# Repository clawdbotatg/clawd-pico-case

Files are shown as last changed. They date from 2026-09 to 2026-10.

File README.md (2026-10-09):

# clawd-pico-case

## What to print (v1.9)

Files are in [`stl/current/`](stl/current/README.md). One case:

| File | Copies | Colour |
|---|---|---|
| [`lid.stl`](stl/current/lid.stl) | 1 | White |
| [`base.stl`](stl/current/base.stl) | 1 | Black |
| [`joystick.stl`](stl/current/joystick.stl) | 1 | Grey |
| [`button.stl`](stl/current/button.stl) | 4 | 2 grey (middle two), 1 green (top right), 1 red (bottom right) |

All PETG. 0.16 mm layers, 4 walls, no supports, no brim, no raft. Lid:
elephant-foot compensation 0.15. Don't rotate the parts; they are already the
right way up (lid face down, base floor down, caps flange down).

**Atomic Wedgie** (RP2040-Plus with a battery): red base with a battery
channel and a black RESET button. See [`stl/atomic-wedgie/`](stl/atomic-wedgie/README.md).

`full-set.stl` is all seven parts on one plate, in one colour. Skip it for a
coloured case.

Everything else in `stl/`, `renders/` and `prints/` is old tests, kept as the
design record. Don't print it.

An MIT-licensed 3D-printed case for a USB-C RP2040 Pico clone (the pink board) plugged into a
Waveshare Pico-LCD-1.3 (240x240 screen, joystick, four buttons). Buttons and
joystick get caps. Made to be printed and sold.

A micro-USB Pico fits too: Austin tested one in the v1.9 case on 2026-10-07,
and the cable and BOOTSEL both work
([log](prints/2026-10-07-micro-usb-fit.md)).

## Why this repo exists

The cases we used before are not ours to sell:

- Tomáš Plass, "Waveshare Pico 1.3 LCD Case", Printables model 1322102, CC BY-NC 4.0.
- Zez0000, "Raspberry Pi Pico 2 Case - Waveshare 1.3\" LCD", MakerWorld model
  3230142, CC BY-NC 4.0. A remix of the Plass case with button and joystick caps.
- Every case file in the `austintgriffith/picowallet` repo derives from those two.

NC means no commercial use. So this case is designed from scratch, from the
hardware and its datasheets only, and released under MIT.

## The rule

Nobody working on this repo opens the designs above, or any other case for
this board, while designing. Not the files, not the photos, not the listing
pages. Every dimension comes from a caliper or a datasheet and is written down
in `MEASUREMENTS.md` before it is used. Every design input is logged in
`PROVENANCE.md`. See `PROCESS.md` for the full protocol and `CLAUDE.md` for the
rules AI agents follow here.

A case for this board will look like the others because the board decides the
size, the screen window, the button holes, the joystick hole and the USB
cutout. That is fine. Shape forced by the hardware is not anyone's property.
What we do not copy is their files and their styling choices.

## Layout

| Path | What |
|---|---|
| `PROCESS.md` | The clean-room protocol, phase by phase |
| `SOURCES.md` | Allowed inputs and forbidden inputs |
| `MEASUREMENTS.md` | The measurement sheet. Every number the design uses |
| `PROVENANCE.md` | Dated log of every design input and who added it |
| `DESIGN.md` | Design decisions, written during the design phase |
| `REPORT.md` | Current state: measurements, design, confidence, open questions |
| `cad/` | build123d source. The design is the source, not the STL |
| `renders/` | `viewer.html`: every part in 3D in a browser, rebuilt from source |
| `research/` | Notes on method: how to get real hardware into 3D |
| `stl/` | Built outputs |
| `prints/` | Print log: what was printed, what fit, what did not |
| `measurements/` | Caliper photos and datasheet drawings |

## Development history (superseded by v1.0)

**Latest: low-lid V3 review, with the lid 1 mm above the glass.**
[Interactive model](renders/v3-low/viewer.html) · [Low-lid design and limitations](reports/2026-09-25-low-lid-experiments.md).
Rear retaining tab replaces the failed side-tab experiment. Not print-approved.
`stl/print/` still contains the OLD tall draft; do not print those files.

### Superseded tall V3 review

**V3 is ready for browser review only; not approved for printing.**
[Interactive model](renders/viewer.html) · [V3 changes and limitations](reports/2026-09-25-v3-review.md).
Flat lid (+4 mm uniformly), restored earlier joystick interface, internal lip,
closed USB port without the lid tab. No V3 print request has been sent.

### Earlier V2 result

**V2 failed its physical fit test. Do not reprint unchanged.**
[What worked, what failed, and correction goals](reports/2026-09-25-v2-review.md).
The V2 description below records the submitted design, not a ready replacement.

Saved designs and print history: [iteration register](ITERATIONS.md).

V1 feedback is [saved with photos](prints/2026-09-24-v1-feedback.md).
V2 / R5 implements all five changes: captive ball joystick, pry notches,
higher/tighter USB-C, wider/taller rectangular buttons and scan-positioned
bottom button access. Fit-test candidate; physical fit unverified. Original geometry;
no third-party case models used. The current target is the measured pink
USB-C board, not an official Pico W/Pico 2 W.

See [V2 preview](renders/r5-preview.png), [interactive assembly](renders/viewer.html),
and [critical review / assembly instructions](REPORT.md). R4 was submitted
to the print inbox; a hold/superseded request was subsequently posted.
Operator acknowledgment and V1's exact printed commit remain unconfirmed.
V2 dispatch and eventual result are recorded in [its print log](prints/2026-09-24-v2.md).
CAD validation is not physical validation; remaining measurements are in the report.

## Build

With Python 3.12 and dependencies in requirements.txt:

```sh
python -m venv .venv
.venv/bin/pip install -r requirements.txt
.venv/bin/python cad/v1_production.py
```

This checks the v1.0 geometry, then writes `stl/v1.0/` and `renders/v1.0/`
(STEP, viewer, validation and hashes). `cad/build.py` and `stl/print/` belong
to the old R4/R5 prototype. Do not print them.

## License

MIT. See `LICENSE`. "Raspberry Pi" and "Waveshare" are their owners'
trademarks. This case is made for their boards and says so descriptively. It
carries no logo but our own.

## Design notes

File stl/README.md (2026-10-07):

**To print a case, use [`current/`](current/README.md). Nothing else here.**

Every other file and folder in `stl/` is an old test, kept as the design
record. `print/` and the loose STLs in this folder are the first prototype
(2026-09-25), not the current case.

Built outputs only; run `.venv/bin/python cad/build.py` from repository root.
Never hand-edit meshes. MIT, like the original source.

`print/` holds base, lid, four button caps, and default joystick cap in print
orientation. Separate button solids on the bed. `fit_samples/` holds alternate
joystick caps named for socket width; try largest first without forcing.
Top-level STL/STEP uses assembled positions and includes illustrative hardware.
`manifest.json` records source/output SHA-256 hashes and tool version.
R4 is an unprinted prototype; print/assembly details in REPORT.md.

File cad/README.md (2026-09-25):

Original build123d CAD. Read `../CLAUDE.md` and `../PROCESS.md` first.
Hardware inputs and R4 choices cite `../MEASUREMENTS.md`; reasons in DESIGN.md.

From repository root: `.venv/bin/python cad/build.py`.
`params.py` defines hardware/choices; `model.py` constructs parts;
`validate.py` checks collision/motion scenarios; `render.py` produces a static
preview from CAD tessellation; `build.py` audits then exports all outputs.
Dependencies are pinned in requirements.txt. Validation is conditional on the
recorded measurements and explicit assumptions; see REPORT.md before printing.

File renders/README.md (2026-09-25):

Generated by `.venv/bin/python cad/build.py` from repository root:

- `viewer.html`: interactive assembly/explode; requires network for three.js.
- `r4-preview.png`: static CAD-derived assembly and interior views.
- `validation.json`: geometric checks, unresolved issues and source hashes.

Images use illustrative hardware proxies, not third-party models. Neither
a rendering nor a passing nominal collision check proves physical fit.

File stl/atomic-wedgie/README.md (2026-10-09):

# Atomic Wedgie: print this

For a Waveshare RP2040-Plus with a battery. Same case as `stl/current/`, with
a different base: a channel in the end wall (away from the USB) for the
battery plug and wire, a BOOT pin hole, and a RESET button.

| File | Copies | Colour |
|---|---|---|
| `base.stl` (this folder) | 1 | Red |
| `reset-button.stl` (this folder) | 1 | Black |
| `../current/lid.stl` | 1 | White |
| `../current/joystick.stl` | 1 | Grey |
| `../current/button.stl` | 4 | 2 grey (middle two), 1 green (top right), 1 red (bottom right) |

All PETG. 0.16 mm layers, 4 walls, no supports, no brim, no raft. Don't
rotate the parts (base floor down, caps flange down).

Assembly: drop the RESET button into its hole from inside the base, flange
up, before the board goes in.

Source: base `cad/aw2_base.py`, RESET button `cad/aw_reset_v3.py`.

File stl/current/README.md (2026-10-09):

# Print this: v1.9 case

| File | Copies | Colour |
|---|---|---|
| `lid.stl` | 1 | White |
| `base.stl` | 1 | Black |
| `joystick.stl` | 1 | Grey |
| `button.stl` | 4 | 2 grey (middle two), 1 green (top right), 1 red (bottom right) |

All PETG. 0.16 mm layers, 4 walls, no supports, no brim, no raft. Lid:
elephant-foot compensation 0.15. Don't rotate the parts; they are already the
right way up (lid face down, base floor down, caps flange down).

`full-set.stl` is all seven parts on one plate, in one colour. Skip it for a
coloured case.

Everything else in `stl/` is old test parts. Don't print it.
Change log: [HISTORY.md](HISTORY.md).

Atomic Wedgie (RP2040-Plus with a battery): different base, red, plus a RESET button. See `../atomic-wedgie/`.

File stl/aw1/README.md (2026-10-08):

# Atomic Wedgie base v1 (RP2040-Plus with a battery)

`base-floor-down.stl`, red PETG. Battery plug slot, BOOT pin hole, and a hole
for a RESET button: print one more `stl/current/button.stl` in red and drop it
in from inside before the board. Lid, joystick and buttons from `stl/current/`.

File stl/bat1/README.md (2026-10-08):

# Battery base (RP2040-Plus with a battery)

`base-floor-down.stl`: the v1.7 base with a 5 × 1 mm slot in the end wall
away from the USB, for the battery plug and wire. Use it with the normal lid,
joystick and buttons from `stl/current/`. Red PETG for the Atomic Wedgie,
same print settings as the case.

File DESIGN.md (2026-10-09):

# Current: V3 fitted shells

J2 socket-first trial: preserve J1 exterior; roundØ3×1 deep then existing
2.01 square×2 deep, exactly as Austin requests. Print cap only before lowering
lid. Pending lowered-lid/hole-centre changes must not alter old print files.

SUPERSEDED by V3-FLAT: whole outer face atz5.1, print FACE DOWN, no supports
or raft. Austin explicitly allows greater screen depth for this trial.
Builder cad/v3_flat.py; reuse button/joystick geometry; lid-only correction.
See JOYSTICK-REVIEW.md for current status; upright plan below is historical.

Complete review and evidence: JOYSTICK-REVIEW.md. Builder cad/v3_fit.py.
Reuse V2 button caps and unchanged J1 joystick; only base/lid print.
Closed V2-aligned USB aperture, no fin; retain pry/reset. Low screen side
rails, local J1-height joystick roof and V2-height button deck. Upright lid
print intent, no supports/raft; mandatory slice review. Historical D7/D8
below are rejected designs, not the current print candidate.

# Historical V3 low-lid revision — D7/D8

Original MIT geometry from this repository's hardware measurements and
Austin's feedback. No external case geometry. Review only, no print approval.

Hard constraint: lid top is glass top +1 mm, z3.05. No joystick collar or
uniform case raise. The rejected tall draft remains saved in v3-review-1.

D7 side retaining tabs cleared5 degrees but failed16 ten-degree lid cases;
that unsuccessful experiment is saved in commit2587340.

D8 uses one rear arm/heel on the joystick cap. The heel is behind the PCB
edge, allowing downward tilt into a local interior pocket, without changing
case height. Earlier full-case4010773 lower socket/neck remain unchanged.
V2 ball diameter7 and small top print flat remain. The cap is still installed
before the lid. The rear heel's thin sections need slicer and strength review.

Button retaining wings now sit beside the switches, below the plunger tops.
The central underside contacts each plunger at measured z2.61. Outside cap
footprint and1.8 mm protrusion remain. Flat top-down printing is planned.

Keep V2-aligned closed USB port, no external lid fin, successful pry notches
and bottom access. Changes and all trial coordinates are recorded in
MEASUREMENTS.md. Required motion scenarios include the full10 degrees,
presses, both pivot assumptions and cap/base/PCB clearance. Inherited
socket/neck versus guessed metal-body collisions remain disclosed.

See reports/2026-09-25-low-lid-experiments.md. Browser review comes before
printing, and no new print artifacts have been produced for this revision.
# J1 isolated joystick test — 2026-09-25

See JOYSTICK-REVIEW.md for the complete current review packet. Original
round-lip cap plus hand-held lid gauge only; D8 rear arm rejected. J1 preserves
the selected V1 socket, has known10-degree motion failures, and is not sent
to the printer. Full-case geometry is unchanged.
## J3 / L1 trial — 2026-09-25

Widen round socket to Austin's 3.50 × 1.10 mm; keep square 2.01 × 2.00 mm
and exterior unchanged. Lower whole flat face 0.90 mm to z4.20, pocket roof
to z3.50. Existing buttons limit further lowering: 0.64 mm roof now remains.
No local boss, supports, USB fin, new base or new buttons. Lip height z2.45
is Austin's estimate for visualization, not proven seating. Iteratively find
motion limit then back off. Full details in JOYSTICK-REVIEW.md.
## L2 / J2 authorized physical trial — 2026-09-25

Move L1 upper roof down 1.00 mm, retaining roof thickness. Keep lower wall
geometry through original glass-clearance height and union translated upper
geometry; preserve contacts, mating skirt and snaps. Face z3.20, joystick
underside z2.50, button underside z2.56. Same base/buttons; exact J2 socket.
User accepts possibly unsuccessful fit; predicted overlaps remain in report,
not suppressed or counted as passes. Print face down with no supports/raft.
## L3 opening correction — 2026-09-25

L2 failed physical closure. Restore L1 thickness/height/pockets and shift only
round opening 1.00 mm toward LCD (CAD negative Y). Fill old throat crescent,
recut at new centre; retain 8 mm diameter and existing lip cavity. No base,
button or joystick changes. Print lid only, face down, supports/raft off.
## L4 alignment refinement

L3 physically overshot. New aperture centre is original X+0.30, Y-0.50:
halfway back from L3 and slightly photo-up with LCD on right. Keep diameter,
height and lip pocket unchanged. Photo-up magnitude is explicitly a trial
choice, not a calibrated measurement. Prepared lid only, not dispatched.
## S1 stronger walls / lower seam — review before printing

Austin's IMG_0834 shows exterior flexible bands and catch windows; he reports
bending during print removal. Replace these with continuous walls and blind
internal detents. Move visible seam to one-third of total height from bottom.
Make walls 3 mm by growing outward, preserving internal board clearances and
fitted control roof heights. A continuous thick perimeter/deeper walls are
intended to improve stiffness without lowering the control pockets again.

Joint uses 3 mm overlap, 1.4 mm socket wall, 0.2 mm gap, 1.4 mm tongue;
small bidirectional ramp catches allow removal without exposed flexible slots.
Minimum exterior skin at blind catches is 1.05 mm. One pry notch remains.
Actual strength, release force and cycle life require testing.

Transfer board support to two base-carried internal rails because the original
wall shelf would otherwise belong to the upper shell and obstruct assembly.
Retain USB port/reset location; extend outside cable recess to compensate for
added wall thickness. L4 opening offset retained. New matching shell pair;
does not fit old base. Interactive review requested; no printer dispatch.
## S2 closure and tactile refinement

S1 field feedback: loose vertical joint and indistinct button tops. Replace
base only: preserve body/rails/ports, swap symmetric triangular detents for
deeper catches with flat holding face, short vertical nose and insertion ramp.
Use existing lid-pocket lower edge to reduce nominal axial travel to0.04 mm;
projection0.50 consumes0.30mm socket flex and leaves0.05mm recess spare.
No claimed FDM accuracy or tested retention force. Small catch overhang needs
slice review. Keep existing lid/pry notch; no new exterior slots.

Caps retain V2 interface, gain0.50mm height and1.20mm rolled top edges to
separate finger contact areas. No change to button spacing or flange height.
Print five parts in PLA; defer PETG/colors until fit iterations finish.
## V1.0 production — final nudges

S2 passed Austin's hands-on test, so the design is frozen apart from three
0.25 mm nudges. Each one moves an opening and keeps its size, so nothing else
in the fit changes. Joystick throat: +y, away from the LCD. It uses L4's
method: fill the old throat through the roof, then cut the new one. The pocket
underneath does not move. USB-C aperture and plug recess: +z. Both stay under
the seam, so the lid needs no change there. The bottom clearance to the
modelled shell drops to 0.10 mm, which is fine because the photo shows the
real receptacle sitting high. Reset hole: -y. Each opening is refilled only
inside the original wall or floor before it is recut, and a check shows
nothing else changed. The buttons and J2 are byte-identical to the tested
parts. PETG shrinks differently from PLA, so the first PETG set is also a
fit check.
## V1.1 USB-end spacer

The v1.0 PETG test showed the stack sliding along the case, and it lines up
best pushed toward the buttons. The holes are therefore right for that
position, so the fix holds the board there and leaves every opening alone.
The USB-end stop face moves 1.0 mm inward: Austin felt about 1.2 mm of play,
and 0.2 mm is kept free so a rigid PCB cannot bind. The model predicts 0.6 mm
of play, so the real board or print differs from the model; his hands win.
The rails would block a full-width lid wall, so the stop is split in two. The
lid gets a lip between the rails that catches the LCD PCB edge; its 45° top
prints face-down with no support. The base gets end stops on top of the rails,
so the board is located before the lid goes on. The USB plug already works
with the board pushed this way, so the plug recess is unchanged.
## V1.3 short USB end (replaces the V1.1/V1.2 spacers)

The spacer added parts (a lid lip and base stops) and still needed both
halves reprinted. Moving the end wall in does the same job with less: the case
gets 0.5 mm shorter, there is no inner lip, and the USB plug sits 0.5 mm closer
to the port. The whole end is rebuilt from the moved datums, so the corners,
the tongue and socket, the rail ends (0.25 mm gap kept), the USB slot and the
plug recess all follow. Everything else is unchanged from v1.0, and a check
confirms that.
## J10 joystick set — 2026-09-29

A direction push on some devices clicks twice. The flange edge behind the push
rises into the lid underside, pivots there and drives the stem down into the
centre switch. Austin wants a joystick-only fix, so the lid is unchanged.
Four caps, numbered I-IV on top, each keep J9's socket and top and change only
what sits under the lid. I and II swap the full disc for four tabs. A tab off
the push axis rises less than the disc rim directly behind the push. I puts
them on the socket diagonals, II on the flats; the stem's turn on the board
is not measured, so one of the two lands on the diagonals. III and IV ride
0.2 lower for more room under the lid, at the risk of a stiffer press (why
J5 raised it). The model gives the tabs 2-3 degrees more tilt before the lid
is touched; the true tilt and seating are unmeasured, so the print decides.
Numerals are engraved, not raised, so the top still feels flat.
## J11 square flange — 2026-09-30

J10 failed: tabs reaching 0.6 past the hole slip through it. Austin's
direction: keep J9 and make its flange a square, thin toward the four push
directions with the corners on the diagonals. The edge behind a push is then a
flat side, which rises less than the old disc rim; the corners sit off the
push axes and still hold the cap in the hole. Two sizes (8.0 and 7.2 across the
flats) and both turns against the socket, because the stem square's turn on
the board is not measured. The pair whose flats face up/down/left/right is the
right turn. A flange that drops lower past the switch body is deferred: it
needs the body height, and it would stop the underside printing flat.
## J12 ride height on J11-III — 2026-09-30

J11-III cured the double click, but the centre press is hard to get without a
direction: the cap sits too low on the stick. J12 raises it the J5 way, with a
shallower round mouth, in four 0.1 steps (V-VIII). Riding higher gives the
press room but lifts the flange toward the lid again, so the set spans both
ends: VIII is back near J9's lid clearance in the model. Austin picks the
lowest one whose centre press is clean.
## J13 split press room from lid room — 2026-09-30

Ride height alone trades press room against lid room, and the working window
sits between VI and VII. The underside of the cap sets press room; the flange
top, where it sits under the lid, sets lid room. J13 thins the flange only
under the lid (0.24 from the hole edge out), so a cap can ride VII-high with
more lid room, and the underside still prints flat on the bed. A smaller square
can't help: its corners must reach past the hole. Round discs just past the
hole close the see-through gap the square leaves; in the model only the 8.6
disc beats VII, and it overlaps the hole by 0.3, so it may be loose. Letters
replace numerals.
## J14 stick fit on J13-O — 2026-09-30

O won J13 on a rough print. J14 prints it clean in three grip sizes around
its 1.90 square (1.85 / 1.90 / 1.95), everything else identical, so the next
test shows both whether O repeats and which grip holds best. Dots replace
letters because small engraved letters print as blobs.
## J16 hard stop and pull-out flares — 2026-09-30

J15's round mouth let the cap slide over the stem's base lip when pushed hard,
and its 0.3 overlap let a hard pull take it out of the lid. J16 cuts the square
grip all the way to the bed face, so the lip stops the cap, and adds four
narrow thin flares on the diagonals. The flares must stay short and thin:
material far out under the lid is what gets caught when the cap tips (the
8.6 disc edge slides into the hole instead), so the chosen flares keep VI's
lid room in the model while reaching 0.8 past the hole.
## J17 gradient on J16 — 2026-09-30

Bigger tabs hold the cap in the lid but get caught under the lid when it tips;
a shallower hole gives a better centre press but lifts the flange toward the
lid. Both push the same way, so J17 walks one path from J16 (tested clean) to
a cap the model is sure double-clicks, in five steps. Austin picks the step
with the best hold and press that still clicks clean.
## V1.8 test: more room for the flange — 2026-10-01

The flange holds the cap in and also causes the centre click when it tips into
the lid. J22's tabs sit on the diagonals, so a diagonal push lifts one straight
into the lid, and they are already too small to hold against a hard pull. The
two needs conflict under the v1.7 roof, so the test gives the flange more room:
lid only (bases unchanged), 0.3 and 0.5 taller, with two J23 caps that hold
harder. A TEST: stl/current stays v1.7 + J22 until Austin picks.
## V1.9 test: screen gap and logo inlay — 2026-10-01

The +0.3 lid works with J22. Two leftovers: the bezel ring had ridden up with
every lid stretch to 1.1 above the glass, so it is filled back to its designed
0.3; and a logo is inlaid in the top face. Face-down printing makes an inlay
natural: the logo is a separate flush part, the slicer prints its first two
layers in a second filament and the lid closes over it. A raised logo would
float the face; an engraving would print as blobs. Still a test.

## Colours (Austin, 2026-10-07)

All PETG. Lid white, base black, joystick grey, middle two buttons grey, top
right button green, bottom right button red. Written into the print table in
`README.md` and `stl/current/README.md` so a printer outside the project can
print the exact case without asking.

## BAT1 battery base (Austin, 2026-10-08)

The RP2040-Plus with a battery has a plug on the non-USB end, centred, and the
wire runs down to the battery wedged under the Pico. The v1.7 base is too
tight there. BAT1 is the v1.7 base with a slot cut 1.0 into the inner face of
that end wall, 5.0 wide (plug 4.45 plus clearance), from the floor to the seam.
It stops at the seam so the lid tongue and its end catch stay whole; the Pico
PCB sits below the seam, so the plug is in the slot's height. 2.0 of wall is
left behind the slot. Lid, joystick and buttons unchanged. Printed in red for
the Atomic Wedgie.

## AW1 Atomic Wedgie base v1 (Austin, 2026-10-08)

BAT1 plus the RP2040-Plus buttons. BOOT stays a pin hole (moved). RESET gets a
real button: the same cap as the lid buttons, dropped in from inside, flange
on the floor, post out through the floor. The switch height can't be read with
a caliper, so it's guessed high (2.65): too high only makes the cap rattle, too
low would hold the board in reset. Same cap means it sticks out 1.79 under the
base, so setting the case down on a table may press RESET. Fit test; iterate.

## AW2 (Austin, 2026-10-08)

The battery slot goes all the way up so the plug slides in from the top. That
cuts through the tongue's end catch, so the catch is removed rather than split
into two side catches: two side catches would need new pockets, so a new lid.
Five catches, current lid. 0.4 of tongue is left behind the slot. AW1 filled
the wrong old hole spot; AW2 fills both.

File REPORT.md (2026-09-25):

# Current status: V3 low-lid browser review

The lid now sits **1 mm above the screen**, not 6.55 mm. Rear joystick
retaining tab replaces the failed side-tab experiment; earlier full-case
socket and V2-sized ball are retained. Button retention is lowered beside
switch bodies. Closed USB opening, pry access and bottom access remain.

[Interactive model](renders/v3-low/viewer.html) ·
[Design, experiments and limitations](reports/2026-09-25-low-lid-experiments.md).

No print approval or printer submission. No updated print files generated.
The files in stl/print are the OLD tall draft; do not print them.

Latest audit and source/output hashes are in renders/v3-low/. Earlier
renders/validation.json and stl/manifest.json describe the tall draft only.
Physical joystick travel, thin-tab strength and support-free slicing still
need verification. CAD checks do not establish physical fit.

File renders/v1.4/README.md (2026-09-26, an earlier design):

# v1.4 review renders

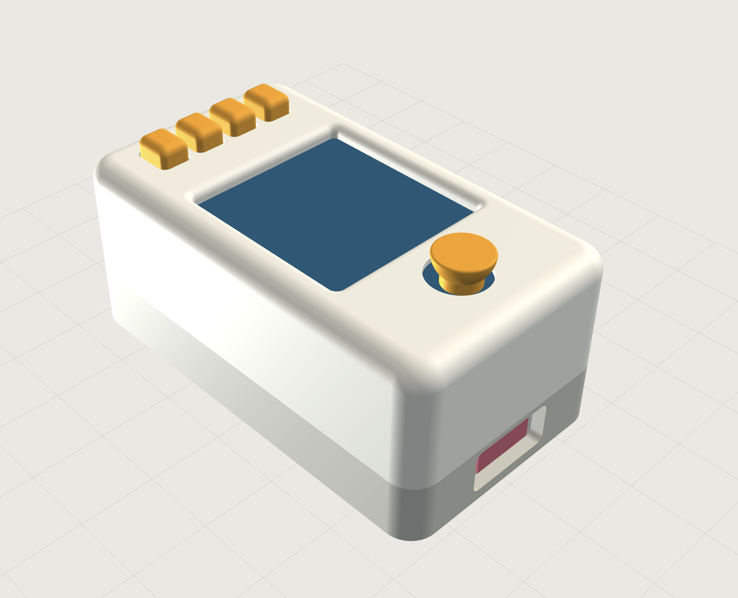
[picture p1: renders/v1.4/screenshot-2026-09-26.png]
v1.4 rounded lid with J4 joystick


Austin's screenshot of the v1.4 3D viewer, 2026-09-26: a lid rounded 3.0 mm
on top, a screen window 1.0 mm smaller with a rounded 1.2 mm bezel, the J4
7.4 mm half-ball joystick, and the v1.3 base. The metadata (EXIF, XMP, ICC)
is removed and the decoded pixels are unchanged; hashes are in
`screenshot-2026-09-26.json`. It is a render, not a photo of a print.

The interactive model is `viewer.html`, built by `cad/v1_4_rounded.py`.

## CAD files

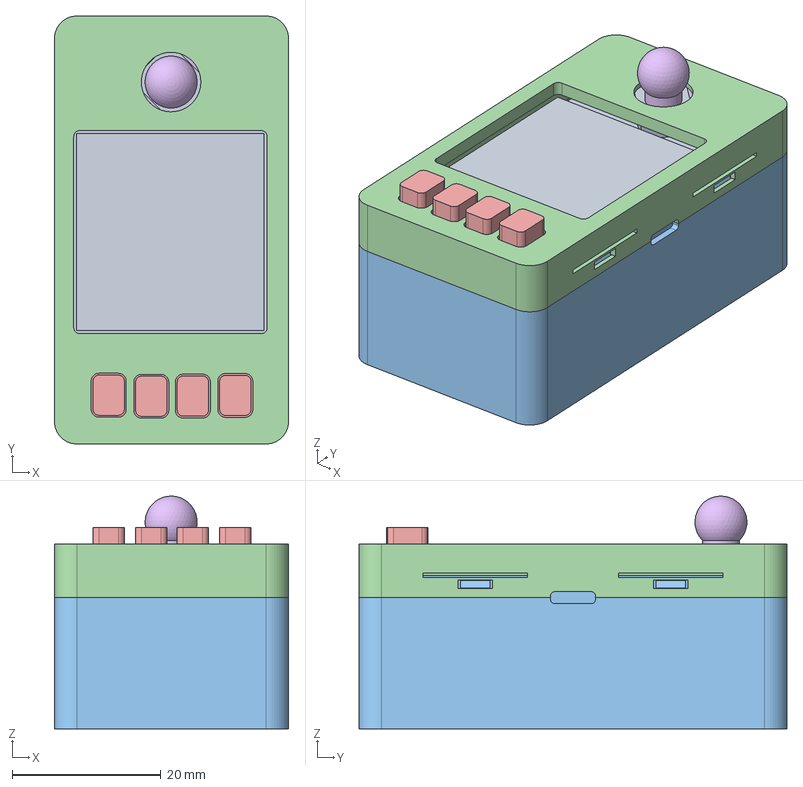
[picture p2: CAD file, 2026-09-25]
renders/j3-low-lid/assembly.step
31.4 x 57.5 x 31.3 mm

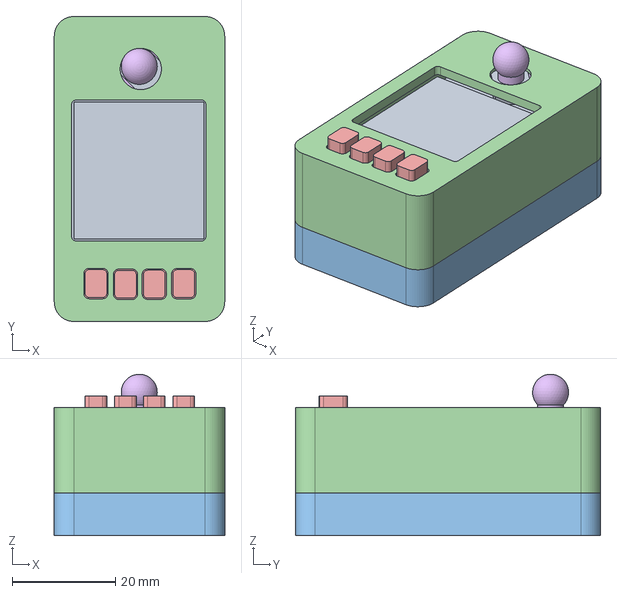
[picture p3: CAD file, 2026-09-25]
renders/s1-strong-shell/assembly.step
33.0 x 59.1 x 31.3 mm

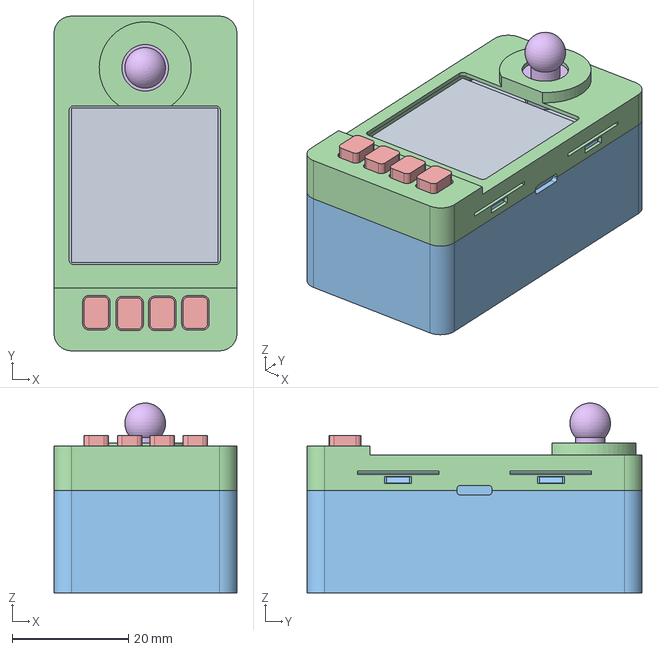
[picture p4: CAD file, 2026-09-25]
renders/v3-fit/assembly.step
31.4 x 57.5 x 32.6 mm

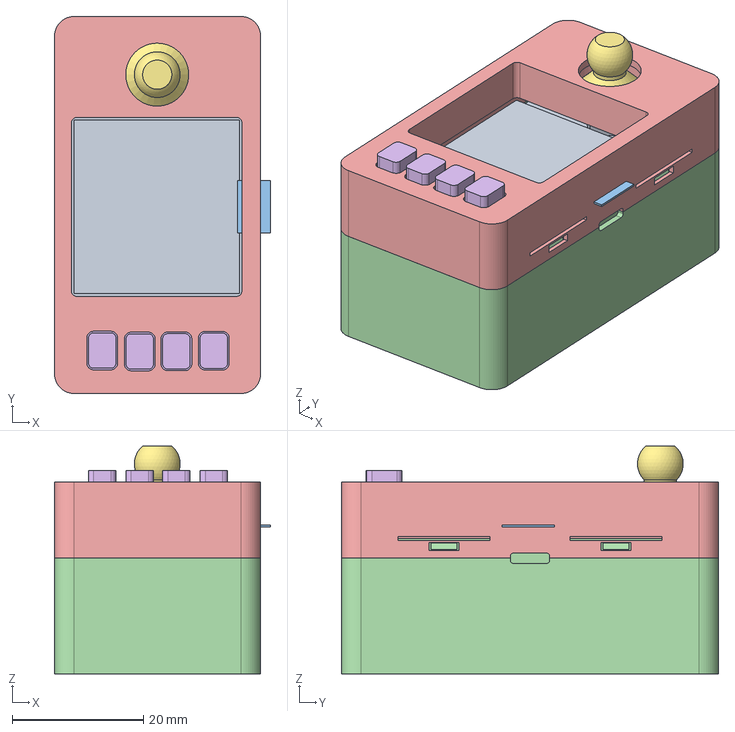
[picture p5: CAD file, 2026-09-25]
stl/assembly.step
32.9 x 57.5 x 34.7 mm

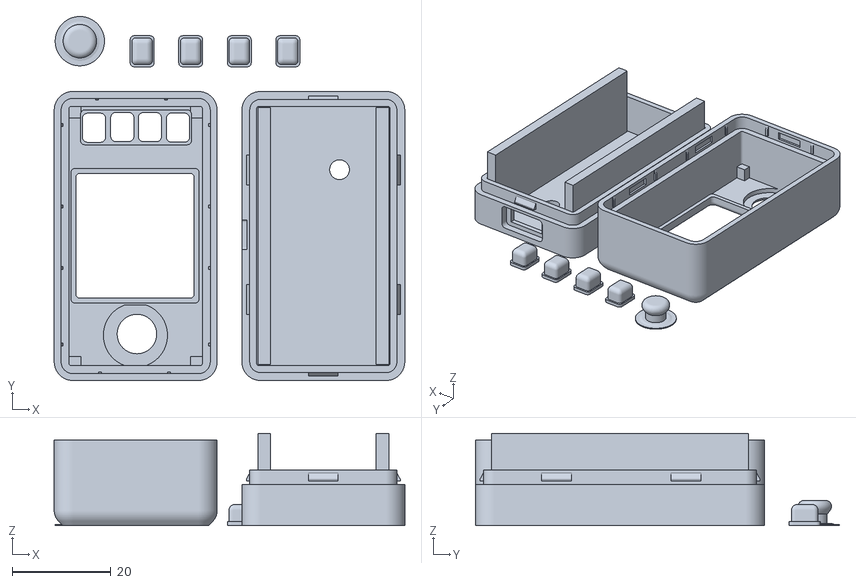
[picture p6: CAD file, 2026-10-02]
stl/current/full-set.stl
71.1 x 73.8 x 18.7

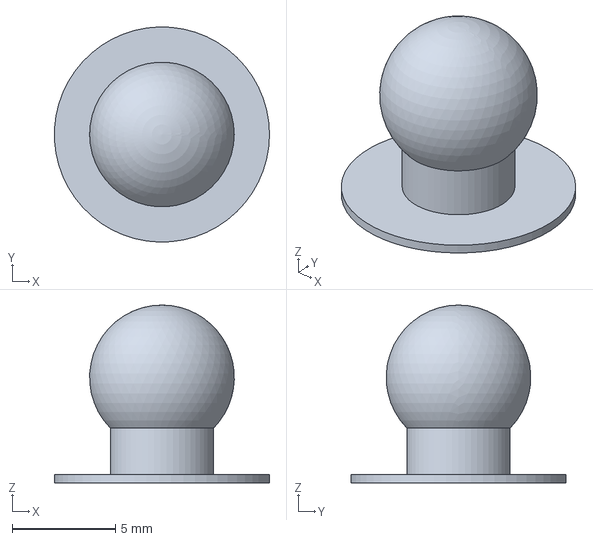
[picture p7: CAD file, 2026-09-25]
renders/joystick-j2/joystick.step
10.4 x 10.4 x 8.60 mm

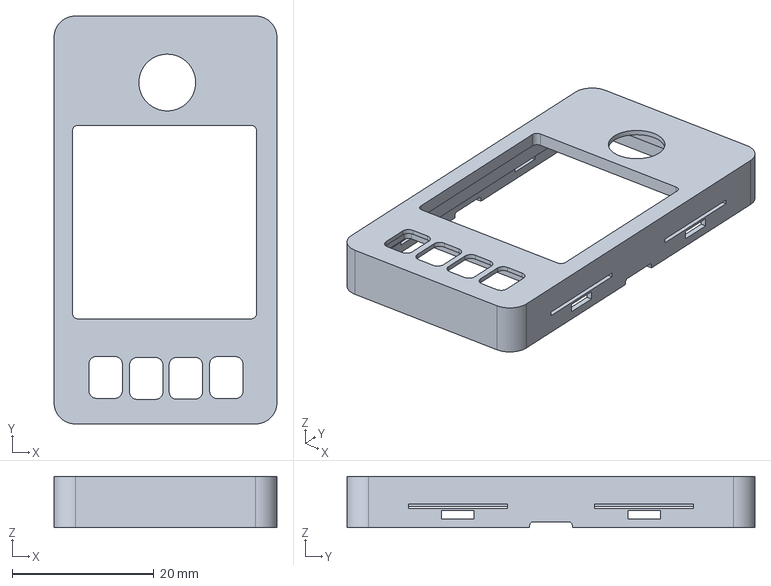
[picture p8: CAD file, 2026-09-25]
renders/l4-alignment/lid.step
31.4 x 57.5 x 7.20 mm

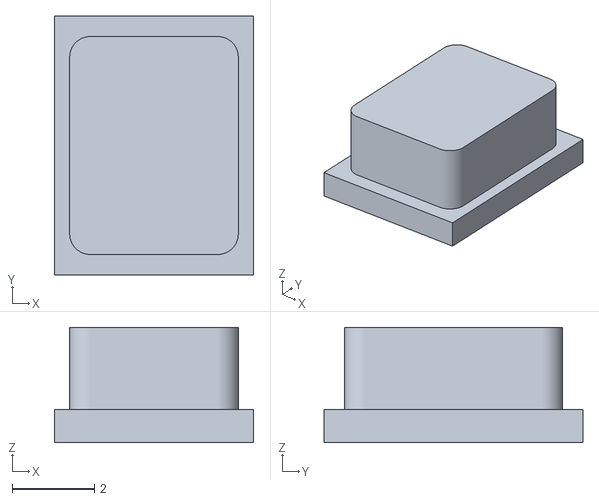
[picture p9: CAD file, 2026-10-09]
stl/atomic-wedgie/reset-button.stl
4.85 x 6.30 x 2.80

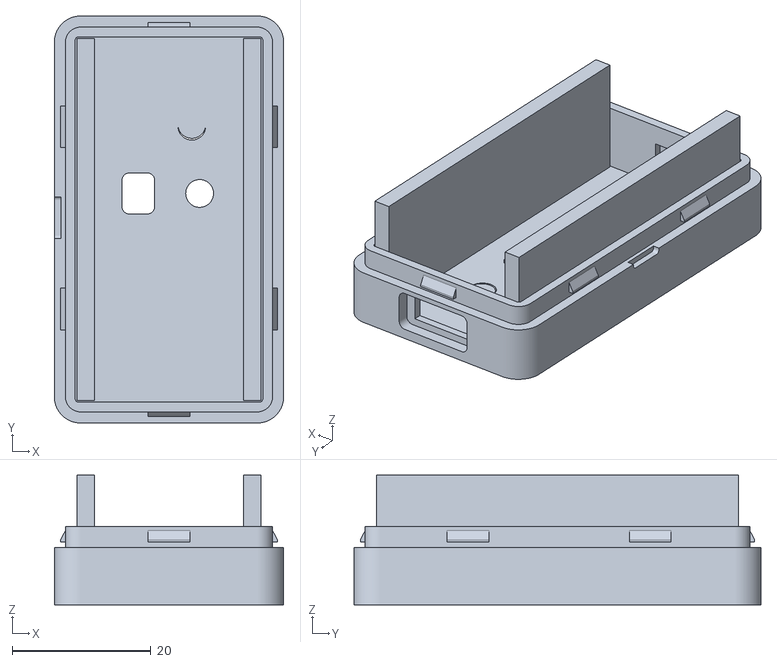
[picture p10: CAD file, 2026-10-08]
stl/aw1/base-floor-down.stl
33.0 x 58.6 x 18.7

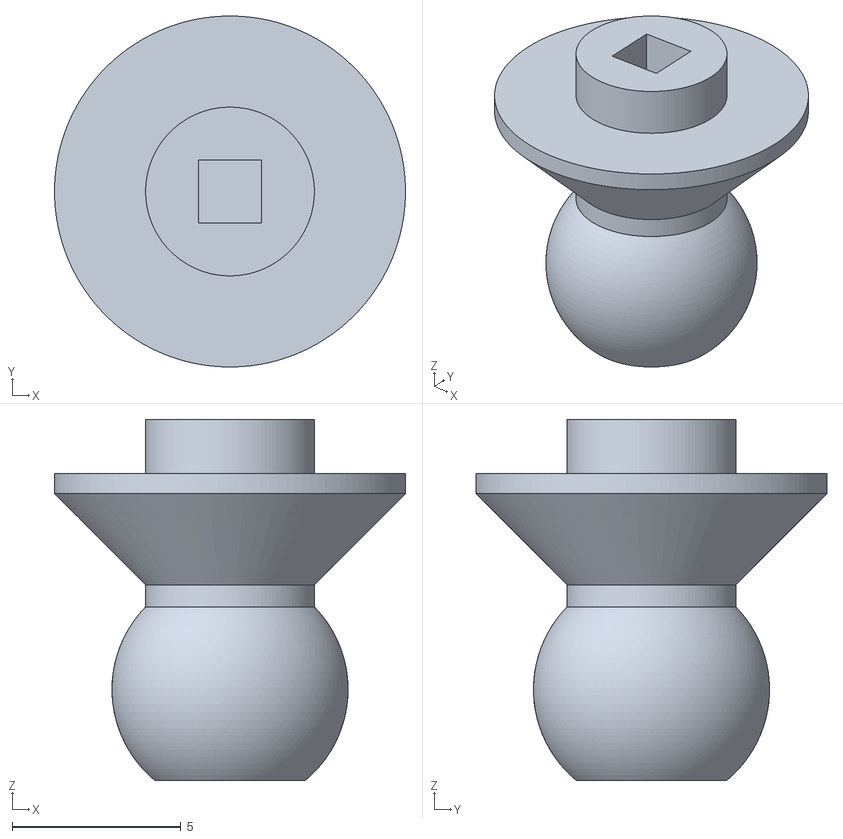
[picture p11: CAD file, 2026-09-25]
stl/fit_samples/joystick_socket_1.86.stl
10.4 x 10.4 x 10.7

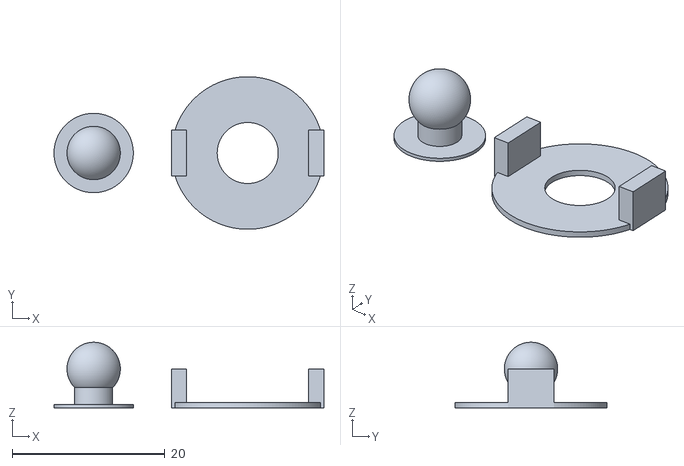
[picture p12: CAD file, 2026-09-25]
stl/joystick-j1/two-part-test.stl
35.4 x 20.0 x 8.60

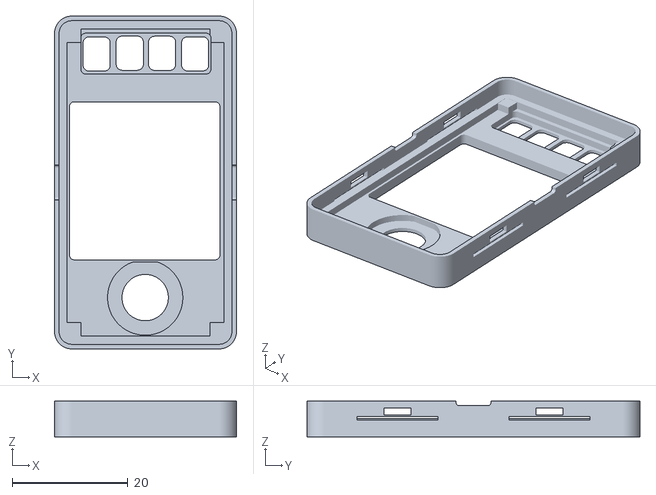
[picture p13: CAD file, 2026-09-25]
stl/l2-j2/lid-face-down.stl
31.4 x 57.5 x 6.20

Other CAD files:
renders/s2-tight-base/assembly.step
stl/s1-full-print/s1-full-case-seven-parts.stl
stl/bat1/base-floor-down.stl
stl/j3-low-lid/lid-face-down.stl
stl/l3-shifted-hole/l3-lid-face-down.stl
stl/l4-alignment/l4-lid-face-down.stl
renders/l2-j2/lid.step
renders/l3-shifted-hole/lid.step
renders/v1.0/assembly.step
renders/v1.1/assembly.step
renders/v1.2/assembly.step
renders/v1.3/assembly.step
renders/v1.4/assembly.step
renders/v1.5/assembly.step
renders/v1.6/assembly.step
renders/v1.7/assembly.step
renders/v3-flat/lid.step
stl/atomic-wedgie/base.stl
stl/base.stl
stl/button_caps.stl
stl/current/base.stl
stl/current/button.stl
stl/current/joystick.stl
stl/current/lid.stl
stl/fit_samples/joystick_socket_1.96.stl
stl/fit_samples/joystick_socket_2.06.stl
stl/fpc_tape.stl
stl/hat.stl
stl/j3-low-lid/joystick-j3.stl
stl/j3-low-lid/lid-and-joystick.stl
stl/joystick-j1/joystick-cap.stl
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

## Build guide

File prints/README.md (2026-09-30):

One file per print: date, material, profile, source revision/hash, results,
and photos. A planned test is not evidence of a successful print.

- Test 1: historical lid/caps request, superseded; no fit result.
- Test 2: historical full-case request, sent; no fit result.
- Test 3 / R4: submitted to HTTP print inbox; print start/result unconfirmed.
- V3 working photos (lid, J1 cap, lineage V1/V2/V3): `v3-photos/`.

Placement (Austin, 2026-09-29): parts printed in the middle of the bed are
very hard to get off. Every drop's notes ask for the parts to be placed away
from the bed centre. The slicer on the print Mac may re-centre a part, so the
request goes in the notes, not only in the STL's coordinates.

Caps (Austin, via the print Mac, 2026-09-30): never a brim or raft on
joystick or button caps; they can't be removed from it.

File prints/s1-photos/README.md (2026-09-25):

# S1 print history photo — received 2026-09-25

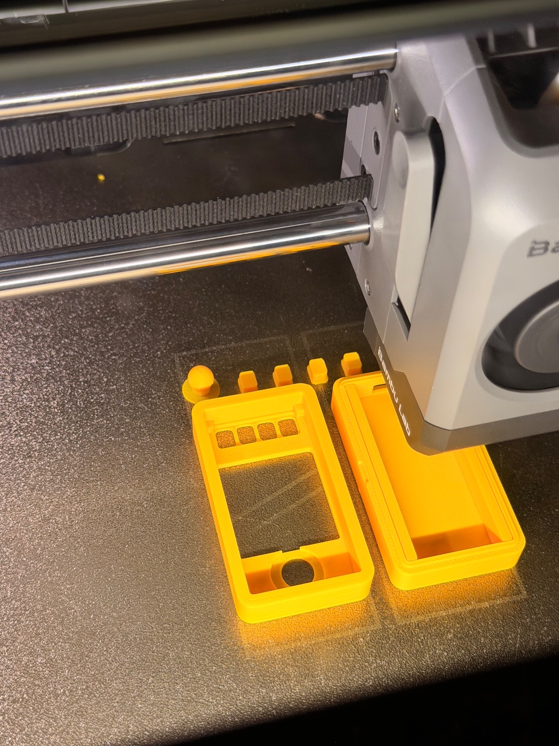
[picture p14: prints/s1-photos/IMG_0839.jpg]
S1 case and controls on the print plate


Austin supplied this photograph of his own case-development process for the
repository history. It shows yellow top/base shells, joystick cap and four
button caps on the printer plate, with the toolhead partly obscuring the base.
The layout is consistent with the S1 seven-part plate submitted from d57302f
and logged in [the S1 print record](../2026-09-25-s1-full-case.md).
This is visual production evidence, not a confirmed completion timestamp,
proof of exact geometry, or a physical fit result. No dimension taken from it.

Received filename: paste-6be18c30-IMG_0839.jpg. Public copy strips EXIF and
Photoshop metadata without changing decoded pixels. Original upload remains
untouched outside Git. Both full hashes and transformation are in
[IMG_0839.json](IMG_0839.json); utility [archive_photo.py](../../tools/archive_photo.py).
No precise capture time or location is claimed. Austin requested inclusion in
this MIT repository; no third-party case image was used as a design input.
## Assembled S1 — IMG_0840

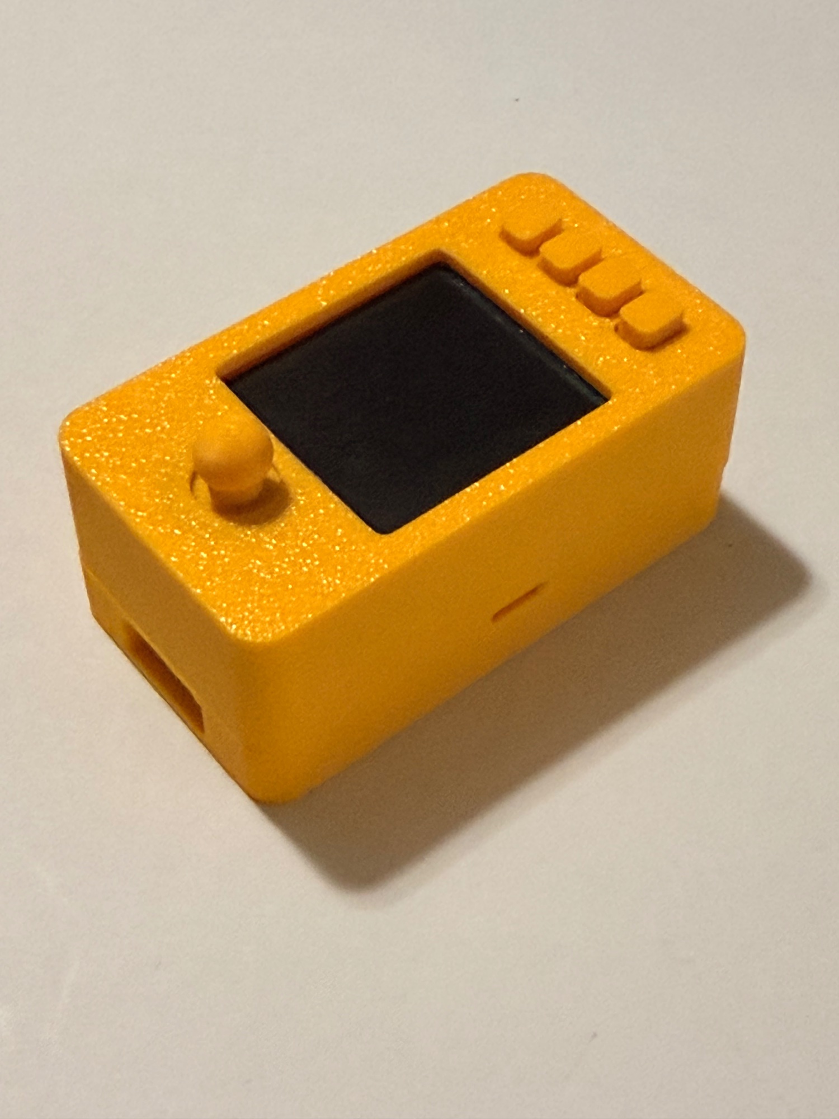
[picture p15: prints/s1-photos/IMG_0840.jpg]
Assembled case with screen and controls


Austin supplies two byte-identical uploads (prefixes 56146ab1 and fed322ed).
Archive one public copy. Shows his assembled yellow case with joystick,
four rectangular button caps, USB opening and single pry notch. Captioned
as S1 from the ongoing test context; no dimensions inferred. His accompanying
feedback: case nearly works, but closure has roughly 0.25 mm play and buttons
need more tactile separation. This records the baseline before S2, not proof
that S2 fits. Metadata removed without changing decoded pixels; original and
public hashes in [IMG_0840.json](IMG_0840.json). Original uploads untouched.

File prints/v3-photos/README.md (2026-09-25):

# V3 working photos, 2026-09-25

Taken by Austin Griffith of our own prints and his own hardware, on his bench,
and handed to the V3 design session on 2026-09-25 "for the record books".
Austin's own photos of this repo's own parts; released under the repo's MIT
license. No third-party case, mesh or image is in any frame.

These are **record photos, not measurements.** No dimension in `cad/` or
`MEASUREMENTS.md` comes from them. The caliper and steel rule in IMG_0817 are
bench tools in the background and show no reading used anywhere.

| File | SHA-256 (first 16) | What it shows |
|---|---|---|
| IMG_0814.jpg | a3c504e8cd4592d8 | J1 joystick cap on the bare stick of the LCD hat, with our flanged retainer/gauge ring (two clip legs) around it. Pink USB-C Pico clone underneath, headers and USB-C visible. No shell. |
| IMG_0817.jpg | 5372915716ba146d | The lineage in one frame: two earlier shells hand-marked in green (V1, V2), a loose retainer ring, and the V3-flat lid (sparkle yellow PLA, face-down print) fitted on the boards with the J1 cap through it. Screen and four button windows. |
| IMG_0822.jpg | 49c2db4e81e69b6f | Side view of the J1 cap on the stick: ball, neck, thin flange. Shows the stick's round collar under the cap's socket, the reason for the J2 stepped socket (`cad/joystick_j2.py`). |
| IMG_0827.jpg | 28bce9e22e3e8e38 | Top view of the V3-flat lid on the board with the cap off: bare stick centred in the lid's joystick hole, screen window edge. |

Full hashes: `sha256sum prints/v3-photos/*.jpg`. The originals were pasted
into the harness as uploads (`paste-*-IMG_08xx.jpg`); these copies are
byte-identical. IMG_0822 and IMG_0827 were first supplied earlier the same
day for the J2 request (see `PROVENANCE.md`, "J2 stepped socket").

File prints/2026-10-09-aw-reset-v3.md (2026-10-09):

# RESET button v3, final (Atomic Wedgie)

The 3-notch v3 test cap without notches: 0.90 shorter than v2, 2.80 tall.
`stl/aw2/reset-button.stl`, SHA256
`095b16b994f369c8c66477ef061b46f239f94a74ba3fea78fe40df0fdf63a684`.
Drop `20261009-102255-reset-button`, 10 copies, black. PETG 0.16, 4 walls,
flange down, no supports, brim or raft, away from bed centre.

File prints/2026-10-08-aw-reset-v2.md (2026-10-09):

# RESET button v2 (Atomic Wedgie)

The 1-notch test cap with the post 0.05 smaller each side and its corners
rounded 0.5 so it drops into the hole. `stl/aw2/reset-button.stl`, SHA256
`a45e4b4a13eac58e183fad01d20cf55d65af0a8d5d778cdf9b5d3d0d03515f23`.
Drop `20261008-205711-reset-button`, 10 copies. PETG 0.16, 4 walls, flange
down, no supports, brim or raft, away from bed centre.

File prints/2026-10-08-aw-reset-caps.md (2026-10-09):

# RESET test caps for the Atomic Wedgie base

Square, flat top. Stick out 1.2 (1 notch), 0.8 (2 notches), 0.4 (3 notches)
below the base. 2 copies each, flange down, PETG 0.16, 4 walls, no supports,
brim or raft, away from bed centre.
Drops `20261008-202342-reset-1-notch`, `20261008-202343-reset-2-notch`,
`20261008-202344-reset-3-notch`. Files in `stl/test/aw-reset/`.

Check: which one doesn't get hit when laid down but still clicks.

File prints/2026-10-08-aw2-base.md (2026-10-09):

# Atomic Wedgie base v2 (red)

AW1 with the battery slot to the top (end catch removed) and the old hole
fully filled. One copy. `stl/aw2/base-floor-down.stl`, SHA256
`4951fae4fe13db5f3d3cd12b5eb6dbba6a7a67e545a14f4c03bd0c34e3cc8301`.
Drop `20261008-192805-base-floor-down`. PETG 0.16, 4 walls, floor down, no
supports, brim or raft, away from bed centre. Needs one red `button.stl`.

Check: plug slides in from the top; the 0.4 strip behind the slot survives;
lid still holds with 5 catches.

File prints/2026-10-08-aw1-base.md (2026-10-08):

# Atomic Wedgie base v1 (red)

BAT1 + BOOT pin hole at the RP2040-Plus spot + RESET button hole (standard
cap, flipped). One copy. `stl/aw1/base-floor-down.stl`, SHA256
`2f36a9ad74ead4e3735656716cd448d7519ffe63d7c8454b0efbdff1fcf035af`. Drop `20261008-155010-base-floor-down`.
PETG 0.16, 4 walls, floor down, no supports, brim or raft, away from bed centre.
Needs one red `stl/current/button.stl`.

Check: RESET clicks and isn't held down; the cap doesn't rattle too much; BOOT
reachable with a pin; the battery plug fits; the lid closes.

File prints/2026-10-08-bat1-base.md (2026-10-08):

# BAT1 battery base (red, Atomic Wedgie)

v1.7 base plus a 5.0 wide, 1.0 deep slot in the non-USB end wall for the
RP2040-Plus battery plug. One copy. `stl/bat1/base-floor-down.stl`, SHA256
`bdc21364ae9587eae687f9e0635e03b18be65a9c92efa4592f1fdb378d189f4e`. Drop `20261008-153833-base-floor-down`.
PETG 0.16, 4 walls, floor down, no supports, brim or raft, away from bed centre.

Check: the plug and wire fit without forcing the board up; the lid closes.

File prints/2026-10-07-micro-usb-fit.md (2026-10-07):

# Micro-USB Pico in the current case (fit test, no new print)

Austin, 2026-10-07: put a micro-USB Pico in one of the current cases (v1.9 lid,
v1.7 base). The cable plugs in and BOOTSEL presses through the base hole. Both
work. No separate micro-USB base needed.

No measurements taken. The board's exact model was not recorded.

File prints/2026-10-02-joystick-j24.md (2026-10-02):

# J24 joystick caps A and B (test, not current), for the V1.9 (+0.3) lid

Both have J24-FIT-2's hole (Austin's pick) and a round 10.0 flange with no tabs
(1.0 past the 8.0 hole all round). They stick up as far as J22. Austin wants
them tried in the +0.3 underwear lid before making the lid taller.

- A: J22's thin flange edge (0.24 from the hole edge out)
- B: 0.4 thick all over (stiffer, 0.16 closer to the lid)

Model tilt before any lid contact, in PCB coordinates, seat 3.22–3.46, pivots
0–2.8 (renders/test/j24/validation.json): J22 8.2° at seat 3.34. A 6.9–10.4°
(about J22's at the measured seat). B 5.1–8.2°. The real tilt is about 8°
(J7, estimate). Prediction: A double-clicks about as often as J22; B more.
Pull-out: B is stiffer.

Separate drops so they can't be mixed: `20261002-132731-joystick-j24-A`
(SHA256 `2bc4d60b…`), `20261002-132731-joystick-j24-B` (SHA256 `b9aef37b…`).
Server hashes match. PETG 0.16, 4 walls, flange down, no supports, raft or
brim, away from the bed centre. No colour or GO.

The taller V2.0 lid + J24 neck + buttons (`cad/v2_0_test.py`) is written but
not run; it waits on this result.

## Result A (Austin, 2026-10-02)

The printer made 9 of A (its own cap default; the drop gave no count). A hard
push still forces A out of the case. B is pending (2 copies requested).

## Result B and verdict (Austin, 2026-10-02)

B clicks the buttons "a little bit too clunky". **A is the one.** In the V1.9
(+0.3) lid, A takes a hard pull and stays in ("if someone pulls on it more
than that, they deserve to break it"). Angles don't hit the middle. The middle
clicks when wanted. The lid with the screen gap fix is "just right", buttons as
they are (original S2), "basically everything is good". The taller V2.0 lid is
not needed.

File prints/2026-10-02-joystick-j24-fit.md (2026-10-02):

# J24-FIT joystick fit test (caps only, not current)

Three J22 caps. The only difference is how far down the tight 1.90 square goes
(J22-GRIP: the stick never reaches the wide part of the hole).

| Dots | Bottom opening | Tight grip |
|---|---|---|
| 1 | J22's (3.2 × 0.5 + funnel) | 0.75 |
| 2 | 3.1 × 0.35 + funnel | 0.95 |
| 3 | 0.25 chamfer only | 1.65 |

Roof at 1.9 and the J22 outside on all three. PETG 0.16, 4 walls, flange down,
no supports, raft or brim, away from the bed centre.

Test on the bare stick: snug push on, stays upside down, centre press clicks
only centre (3 dots may sit on the collar), clamp the height.

`stl/test/j24-fit/joystick-j24-fit-plate.stl`, SHA256 `f7ae9cd16da29d605313ec9dedb5d89609c1a0caa7c44c2071abd31ee64d96cf` (server hash matches). Drop `20261002-115941-joystick-j24-fit-plate`, no colour or GO.

The printer made 3 of each in a ring (the first try failed at layer 17). The
top dots printed unreadable; caps were told apart by the hole underneath.

## Result (Austin, 2026-10-02)

3 (square almost to the bottom) is ruled out: pressing it also clicks other
directions, so the in-press isn't clean. The wide end has to stay. **2 wins** (3.1 × 0.35 opening, 0.95 grip): the centre press clicks only
centre. The cap still rips out of the case: the flange is too small. Austin
would also like the stick a little taller and the top grippier.

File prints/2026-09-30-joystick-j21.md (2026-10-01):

# J21 joystick test pair (wide mouth, deeper)

J20 (wide 3.2 opening for the first 0.5 mm, J17-B tabs) with the hole
1.9 mm deep (1 dot) and 2.0 mm deep (2 dots). PETG 0.16, 4 walls, flange
down, no supports, raft or brim, away from the bed centre.

`stl/v1.4/joystick-j21/joystick-j21-plate.stl`, SHA256 `987ac2961bd4d0b7032ec7c5413e23ce34a2962f17bb30b262c07aecf1011ffa` (server hash matches). Drop `20260930-204346-joystick-j21-plate`, no colour or GO.

## Result (Austin, 2026-09-30)

**Number 1 (1.9 deep) is the one.** With a flat top it is J22, the current joystick.
Production drop `20260930-211620-joystick` (stl/current/joystick.stl, SHA256 `b9aeb782310bfc8226284111798b225584c5e29f7523dd47e9c6cdfa69d4067a`); J15 drop marked do-not-print.

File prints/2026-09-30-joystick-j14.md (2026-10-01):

# J14 joystick set 1 2 3 (J13-O, three stick fits)

J13-O (8.6 round flange, lift 0.6, thinned edge), marked with dots on top:

- 1 dot: grip 1.85, one step tighter
- 2 dots: grip 1.90, same as O
- 3 dots: grip 1.95, one step looser

PETG 0.16, 4 walls, flange down, no supports or raft, parts away from the bed
centre. Thin flange edges: peel gently.

Test with the lid on: centre press clicks alone; 10 pushes each direction,
no centre click; the cap stays on the stick.

`stl/v1.4/joystick-j14/joystick-j14-plate.stl`, SHA256 `ded38bff48c0344c1eafc20d5adc8a4a77b6b1cfff7e8bd7e60c619c555502fd` (server hash matches). Drop `20260930-112533-joystick-j14-plate`, no colour or GO.

## Result (Austin, 2026-09-30)

**Number 2 (two dots, grip 1.90) is the one**: it stays on the stick best and
gives the best centre press. It is the new joystick (`stl/current/joystick.stl`).
This plate was printed with a raft; Austin does not want one.
Production drop `20260930-115222-joystick` (stl/current/joystick.stl, no raft), copies on Austin's word.

Superseded by J15 (flat top), drop `20260930-122840-joystick` (SHA256 `8532d64100ffb34a4267d66b1b4375925a708c59f131fd28cba8066931b81c00`); the two-dot drop is marked do-not-print.

## J15 result (Austin, 2026-09-30, after 12 printed)

Pushed hard, the cap's round mouth slides down over the stick's thick base and
the centre press stops working; pulled hard, it comes out through the lid (the
8.6 disc overlaps the hole by only 0.3). Next: J16.

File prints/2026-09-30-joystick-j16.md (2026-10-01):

# J16 joystick test

J15 with (1) the square hole all the way down, so a hard push stops on the
stem's thick base instead of sliding over it, and (2) four small flares at
NE/NW/SE/SW on the round flange, so a hard pull can't take it out of the lid.
Flat top, no marks.

PETG 0.16, 4 walls, flange down, no supports, no raft, no brim, away from the
bed centre. Thin flange edge and flares (0.24): peel gently.

Test with the lid on: hard push still clicks the centre; hard pull doesn't
come out; 10 pushes each direction, no centre click.

`stl/v1.4/joystick-j16/joystick-j16.stl`, SHA256 `0e9698a90a066485e349bb1dc3483cee9b52f28d669afd65910322f1af5ec127` (server hash matches). Drop `20260930-131345-joystick-j16`, no colour or GO.

## Result (Austin, 2026-09-30)

No double click. The hole needs to be shallower, and the tabs about two to
three times bigger. Next: J17.

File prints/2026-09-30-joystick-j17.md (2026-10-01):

# J17 joystick test set A–E (dice dots on top)

J16 with bigger tabs and a shallower hole, stepped together:

| Cap | Dots | Hole shallower | Tabs vs J16 | Model lid room |
|---|---|---|---|---|
| A | 1 | 0 | 1.3× | 16.6° |
| B | 2 | 0.05 | 1.55× | 15.1° |
| C | 3 | 0.10 | 1.8× | 13.7° |
| D | 4 | 0.15 | 2.05× | 12.5° |
| E | 5 | 0.20 | 2.3× | 11.4° |

J16 17.6° (no double click); VII 15.8° (double click). PETG 0.16, 4 walls,
flange down, no supports, raft or brim, away from the bed centre.

Test with the lid on: hard pull stays in; centre press clicks alone; 10 pushes
each direction, no centre click.

`stl/v1.4/joystick-j17/joystick-j17-plate.stl`, SHA256 `818fb01002706e70102a72f0f992c47e2c5b21cb42f0453294eec36d2a7bcc3a` (server hash matches). Drop `20260930-164221-joystick-j17-plate`, no colour or GO.

## Result (Austin, 2026-09-30)

Even the shallowest hole: pressing the cap clicks all five switches, while the
bare stick clicks only the centre. The cap's bottom lands on the stick's
collar. The hole is not nearly shallow enough. Next: J18.

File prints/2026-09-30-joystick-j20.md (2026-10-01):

# J20 joystick test (one cap, flat top)

J19-2 (hole 1.5 deep, J17-B tabs) with the first 0.5 mm of the hole a wide
round opening (3.2) that fits over the stick's collar, then a 45° step into
the 1.90 square. The square grips only the top ~1 mm of the stick.
PETG 0.16, 4 walls, flange down, no supports, raft or brim, away from the bed
centre.

`stl/v1.4/joystick-j20/joystick-j20.stl`, SHA256 `5fe0c83564ae6fea942f657a5800858632e8dc73e1a2830dd94581fbbd17d996` (server hash matches). Drop `20260930-202205-joystick-j20`, no colour or GO.

## Result (Austin, 2026-09-30)

1.5 is not nearly deep enough. Next: J21 at 1.9 and 2.0.

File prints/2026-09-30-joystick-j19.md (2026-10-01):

# J19 joystick set 1–5 (shallower holes, dice dots on top)

| Dots | 1 | 2 | 3 | 4 | 5 |
|---|---|---|---|---|---|
| Hole depth mm | 1.6 | 1.5 | 1.4 | 1.3 | 1.2 |

J17-B tabs. The shallowest grip only ~1 mm of the stick. PETG 0.16, 4 walls,
flange down, no supports, raft or brim, away from the bed centre.

`stl/v1.4/joystick-j19/joystick-j19-plate.stl`, SHA256 `fc840d6f5bab72ece5bd1714af98a9a28663c9e95d63c40e418f88de12c82a4b` (server hash matches). Drop `20260930-192744-joystick-j19-plate`, no colour or GO.

## Result (Austin, 2026-09-30)

"Still not quite right." Next: J20 = number 2 (1.5) with a wide mouth.

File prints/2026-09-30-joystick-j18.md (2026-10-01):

# J18 joystick set 1–6 (hole depth, dice dots on top)

J17-B's tabs on six hole depths (cap bottom to where the stick tip stops):

| Dots | 1 | 2 | 3 | 4 | 5 | 6 |
|---|---|---|---|---|---|---|
| Hole depth mm | 2.2 | 2.1 | 2.0 | 1.9 | 1.8 | 1.7 |

Goal: pressing the cap clicks only the centre (the cap's bottom must not reach
the stick's collar, ~2 mm below the tip). Riding higher may bring back the
direction double click (model). PETG 0.16, 4 walls, flange down, no supports,
raft or brim, away from the bed centre.

`stl/v1.4/joystick-j18/joystick-j18-plate.stl`, SHA256 `61aeea5be20831c8af5f2bf669025fdbd4b9275639f30c3c4d80745d1423a9b7` (server hash matches). Drop `20260930-183418-joystick-j18-plate`, no colour or GO.

## Result (Austin, 2026-09-30)

Not even 6 (1.7) is shallow enough: pressing still clicks all five. Next: J19.

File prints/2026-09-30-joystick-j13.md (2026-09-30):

# J13 joystick test set H T L X O E

Between VI (clean directions, weak centre) and VII (clean centre, some
double clicks). Letters on top.

- H: square, halfway between VI and VII
- T: square, VII height, flange edge thinned under the lid
- L: square, a bit above VII, thinned
- X: square, higher still, thinned
- O: round 8.6, VII height, thinned (may be loose in the hole)
- E: round 8.8, VII height, thinned

PETG 0.16, 4 walls, flange down, no supports or raft, parts away from the bed
centre. The thinned edges are 0.24 thick: peel gently.

Test with the lid on: centre press clicks alone; 10 pushes each direction,
no centre click.

`stl/v1.4/joystick-j13/joystick-j13-plate.stl`, SHA256 `86e3dec98753b39a319d1ef0be7a5b18475027b4da5ded1c09334a83420494cb` (server hash matches). Drop `20260930-105620-joystick-j13-plate`, no colour or GO.

## Result (Austin, 2026-09-30)

The print was rough: one square cap failed as spaghetti, and the letter
grooves came out messy (O reads like a D). Photos IMG_0980-0982. **O is the
best one**: 8.6 round flange, lift 0.6, thinned edge. Not yet a count-tested
result (10 pushes per direction).

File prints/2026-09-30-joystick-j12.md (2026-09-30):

# J12 joystick test set V–VIII (J11-III riding higher)

J11-III stopped the double click, but the centre press is hard to get
without a direction. J12 makes the hole for the stick shallower, so the cap
rides higher: V +0.1, VI +0.2, VII +0.3, VIII +0.4 mm over III. Flange and
top are III's. Numbers engraved on top.

`stl/v1.4/joystick-j12/joystick-j12-plate.stl`, drop recorded below.
PETG 0.16, 4 walls, flange down, no supports or raft, parts away from the bed
centre.

Test with the lid on: the centre press should click alone; up/down/left/right
should still click only the direction (10 pushes each). The higher ones bring
the flange nearer the lid, so VIII may double-click again. Keep the lowest one
with a clean centre press.

Drop `20260930-092006-joystick-j12-plate`, SHA256 `c9a0ad6c4ff53212c846e068e6f8ed23437de9a2ede81041f7de79f4676f1bd0` (server hash matches), no colour or GO.

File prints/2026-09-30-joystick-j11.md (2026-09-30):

# J11 joystick test set I–IV (square flange)

J10's tabs fell through the lid hole. J11 is J9 with its round flange
replaced by a square: flat sides toward up/down/left/right, corners toward
the diagonals. Numbers engraved on top.

- I: 8.0 across the flats, in line with the socket square
- II: 8.0, turned 45°
- III: 7.2 across the flats, in line
- IV: 7.2, turned 45°

`stl/v1.4/joystick-j11/joystick-j11-plate.stl`, SHA256 `6de819b06ec61e5ef790f2d5ea0f2c7281e1700debff67e541dcf9cfc53eaf8c` (server hash matches).
Drop `20260930-082611-joystick-j11-plate`, no colour or GO. PETG 0.16, 4 walls,
flange down, no supports or raft, parts away from the bed centre.

Test: put a cap on the stick. Keep the pair (I+III or II+IV) whose flat sides
face up/down/left/right. With the lid on, push each direction 10 times and
count the double clicks; check the press-in still clicks once.

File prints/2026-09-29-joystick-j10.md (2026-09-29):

# J10 joystick test set I–IV

Fix for the double click: a direction push clicks the direction, then a
little farther clicks the centre, because the flange edge behind the push
rises into the lid underside. The number is engraved on top of each cap.

- I: four tabs on the socket diagonals
- II: four tabs in line with the socket flats
- III: J9 full disc, riding 0.2 lower
- IV: I's tabs, riding 0.2 lower

`stl/v1.4/joystick-j10/joystick-j10-plate.stl`, SHA256 `8ecab95751cf036b6af36888e086ec3edb05337b321c284afa6bceec5637e228` (server hash matches).
Drop `20260929-174339-joystick-j10-plate`, no colour or GO. PETG 0.16, 4 walls,
tabs/flange down, no supports or raft. Notes ask for the parts away from the
bed centre.

Test on every device, lid on: push each direction 10 times and count the
centre clicks; also check the press-in still clicks cleanly (III/IV ride
lower). If I works and II doesn't (or the other way), that also tells which
way the stem square is turned on the board.

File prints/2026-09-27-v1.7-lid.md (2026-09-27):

# v1.7 lid — locking pockets

One lid, dropped with no colour or GO. It is the v1.6 lid with 6 catch
pockets (0.55 deep) and the pry half filled; it pairs with the v1.7 base drop
`20260927-112055-base-floor-down`.

Source 1867c27, `stl/v1.7/lid-face-down.stl`, SHA256 `3545719d59f4f3d9e22816413f280d5eeea3309813795c2f23a0cffae91a70df`. Drop `20260927-115227-lid-face-down`.
PETG, 0.16 mm, 4 walls, no supports, no raft, face down, elephant-foot
compensation 0.15.

Check: it closes without forcing, can't be opened by hand without the slot,
opens with a thumbnail or tool at the base slot, and the smooth top edge.

## Replaced before printing

The same lid, with smooth LCD-window and joystick edges, is re-dropped as
`20260927-115641-lid-face-down` (source d4c4356, SHA256 `0e5f2114bfcb509517f89357d5d75bd8e0ac02ec1e038387c751a685b5f3004c`). The first drop is marked as superseded.

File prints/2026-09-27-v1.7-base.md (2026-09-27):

# v1.7 base — locking catches

One base, dropped with no colour or GO. It has 6 catches hooking 0.5 mm and
the base-only pry slot. It needs the v1.7 lid (not printed yet).

Source a317368, `stl/v1.7/base-floor-down.stl`, SHA256 `8b57fa0594fdab7f7bf01c5c8fc0d289bceda05da821e47d727440e18381530d`. Drop `20260927-112055-base-floor-down [33.04, 58.6,`.
PETG, 0.16 mm, 4 walls, no supports, no raft, floor down.

Check: the catch undersides print clean (0.7 overhang) and the slot is
usable. The fit test needs the v1.7 lid.

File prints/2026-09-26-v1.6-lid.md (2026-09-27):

# v1.6 lid — smooth top edge

One lid, dropped with no colour or GO. It is v1.5 with the 45° band at the
top edge. No supports, no raft; elephant-foot compensation 0.15 mm is
requested in the settings.

Source 3a61ca7, `stl/v1.6/lid-face-down.stl`, SHA256 `9bb5ca1e823b298ff9e16dfed54fd51728e78861857eed8baee7eef13e5bd165`. Drop `20260926-213759-lid-face-down`.

Check: the line where the top meets the curve is smooth, and the fit, ribs
and joystick are the same as v1.5.

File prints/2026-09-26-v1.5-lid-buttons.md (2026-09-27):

# v1.5 taller lid + buttons

Dropped with no colour or GO. The v1.5 lid needs the v1.5 buttons (4 per
case); the old buttons would sit 0.5 mm loose.

| Part | File | SHA256 | Drop |
|---|---|---|---|
| Lid (face down) | `stl/v1.5/lid-face-down.stl` | `f8743db2c8019651ddb68d7c2174963481f8f13406bbe0492ac7425e3b2d8b23` | `20260926-204210-lid-face-down` |
| Button (×4 per case) | `stl/v1.5/button.stl` | `1affb504b681088e27f415af12d9499cd2c98b9a87a3852b8e74d7d73ecf09cb` | `20260926-204210-button` |

Source 1905568. PETG, 0.16 mm, 4 walls, no supports, no raft. It fits the existing
v1.3 bases and the J9 joystick.

Check: direction pushes no longer click the centre, the buttons don't rattle,
the lid snaps firmly (ribs), and the screen bezel sits close to the glass.

## Result

Austin: "everything works fine." The v1.5 lid works with the original
buttons, which he tried and says are fine, so the thicker-flange v1.5 button
was dropped (file removed, inbox drop marked superseded). v1.5 is promoted to
`stl/current/` and tagged v1.5.

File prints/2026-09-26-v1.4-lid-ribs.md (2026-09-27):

# v1.4 lid with crush ribs

One lid, dropped with no colour or GO. It has 12 vertical ribs inside the
skirt that grip the base tongue by 0.15 mm, and it fits the already-printed
bases.

Source 68926ef, `stl/v1.4/lid-face-down.stl`, SHA256 `9843e62e815e1642f67ed093768b337ea9793035d00dfdd8a184f770626fce08`. Drop `20260926-203016-lid-face-down`.
PETG, 0.16 mm, 4 walls, no supports, no raft, face down.

Check: it snaps on firmly with no rattle, it still opens at the pry notch,
and there are no cracks in the skirt. If it is too tight, go to 0.10; if too
loose, go to 0.20.

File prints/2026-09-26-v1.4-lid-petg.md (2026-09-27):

# v1.4 lid — white PETG (look trial)

Austin asks for one v1.4 lid to try the rounded corners. He gave no colour,
so it uses white PETG from bay 2, the same as the earlier lids. The top
perimeter is rounded 3.0 mm, and the screen window is 1.0 mm smaller per side
with a rounded 1.2 mm bezel. The fit is v1.3, so it mates with the v1.3 base.

Source c2425d0 (no ribs; file in that commit), `stl/v1.4/lid-face-down.stl`, SHA256
`3059615094d122bf546c889ccafbb685b5574a490b64245cd719f1f88cdb2aa0`.
33.04 × 58.60 × 16.56 mm. PETG, 0.16 mm, 4 walls, no supports, no raft,
face down.

Sent to the HTTP inbox as `20260926-134730-lid-face-down` with a GO. Status:
new. Print start unconfirmed.

Check: the look and finish of the rounded edges on the bed side, that the
bezel does not cover lit pixels, and the snap onto the v1.3 base.

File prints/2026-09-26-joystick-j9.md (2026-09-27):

# J9 joystick ×3 — consistency check

J9 = J7-B's hole + J8-3's round edge, with no notches. Austin reported that
J8-3 clicked centre + up every time, although its socket is identical to B's
(checked in CAD), so the likely cause is print variation. Three copies are
dropped (copies=3, no colour or GO).

`stl/v1.4/joystick-j9.stl`, SHA256 `8244979877362cfb7588a9f663dbcd35ba35dad203c182e96bb0e96ea0bc9318`. Drop `20260926-195839-joystick-j9`.

Read the result like this: all three clean means J8-3 was a one-off; all
three centre + a direction means a real cause to find.

Austin: "just send one", and he will tell the printer how many. The same file
was re-dropped with copies=1: `20260926-195928-joystick-j9`. The copies=3 drop is marked as
superseded.

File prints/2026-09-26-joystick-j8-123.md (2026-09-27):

# J8 joystick test set 1/2/3 (variations on J7-B)

Dropped with no colour or GO. Flange notches: 1 = smaller flange (9.2),
2 = smaller flange + rides 0.5 higher, 3 = rounder top edge (1.2).
All use the 1.90 printable socket.

`stl/v1.4/joystick-j8/joystick-j8-123-plate.stl`, SHA256 `43b22b41a63f8850ad664b8204426c97ee7f4694aaad19b668a9718b36959b5d`. Drop `20260926-193415-joystick-j8-123-plate`.
PETG, 0.16 mm, 4 walls, no supports, no raft, flange down.

Check: a direction push gives only the direction (no centre), a centre push
gives only the centre, and the fit is as snug as B.

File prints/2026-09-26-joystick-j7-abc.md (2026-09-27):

# J7 joystick test set A/B/C (printable socket)

Three guesses on one plate, dropped with no colour or GO. They replace J6.
The flange notches show which is which: 1 = A (1.95 socket), 2 = B (1.90),
3 = C (1.95 plus thumb dish). The socket has no flat overhangs.

`stl/v1.4/joystick-j7/joystick-j7-abc-plate.stl`, SHA256
`7da50b712ffe3bc3a5b92c081906429d9feaee2817a414b24cf264a367936f74`,
39.2 × 10.4 × 5.1 mm. Drop `20260926-164406-joystick-j7-abc-plate`.
PETG, 0.16 mm, 4 walls, no supports, no raft, flange down.

Check: a clean socket with no strings, a clean centre click, a snug fit, and
free tilt.

## Result

Austin prefers B (middle, 2 notches, 1.90 socket) and asked for one more to
confirm. One J7-B was dropped with no colour or GO:
`stl/v1.4/joystick-j7/joystick-j7-b.stl`, SHA256 `9642da2a7447b7ac1901510c7d582ceb871a685471a6db2d7a18548d0ecf6537`.

J7-B confirm print: "not it" (Austin). Next he tries A (1 notch, 1.95). One
J7-A was dropped with no colour or GO:
`stl/v1.4/joystick-j7/joystick-j7-a.stl`, SHA256 `415547294c60e96cb868cd29aebd14e2ab6f8aef42f885c0c7b33f409e5f0cd4`.

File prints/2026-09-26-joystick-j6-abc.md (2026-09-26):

# J6 joystick test set A/B/C

Three caps on one plate, dropped without a colour or GO; Austin starts it.
The flange rim notches tell them apart: 1 = A, 2 = B, 3 = C.

| Cap | Notches | Square socket | Top |
|---|---|---|---|
| A | 1 | 1.95 | flat |
| B | 2 | 1.90 (tightest) | flat |
| C | 3 | 1.95 | 0.4 mm thumb dish |

`stl/v1.4/joystick-j6/joystick-j6-abc-plate.stl`, SHA256
`599c83ae5b730749778da88f72313d8c96faf0cdecc259fac9272e1dd1751735`,
39.2 × 10.4 × 5.1 mm. Drop `20260926-155748-joystick-j6-abc-plate`.
PETG, 0.16 mm, 4 walls, no supports, no raft, flange down.

Check each one: a clean centre click only (no direction), a firm fit with no
rocking, and the tilt directions still work.

## Result — socket full of strings (IMG_0887)

The photo shows cap B (2 notches) from underneath, with loops of loose
filament inside the socket. Cause, owned by Claude's design: printed flange
down, the socket has two flat features in mid-air. There is a ledge where the
3.0 round mouth narrows to the square, and a flat roof over the square. The
printer has to bridge both over nothing, and PETG strings and droops there.
J2 has the same ledge and roof, so a clean J2 was partly luck. It is not a
printer fault. The next socket must be self-supporting (45° transitions, no
flat overhangs), and that needs the real stem shape measured.


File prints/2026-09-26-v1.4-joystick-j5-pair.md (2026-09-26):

# J5 joystick test pair

Two J5 caps for a side-by-side press-in and tilt test. Both were dropped in
the print inbox without a colour or GO; Austin starts the print himself.

| Variant | File | SHA256 | Drop |
|---|---|---|---|
| lift 0.3 | `stl/v1.4/joystick-j5-lift-0.3.stl` | `e344aae00ae803b8bcb927626976555e200b857604099f8d6984ba214df2d145` | `20260926-153428-joystick-j5-lift-0.3` |
| lift 0.5 | `stl/v1.4/joystick-j5-lift-0.5.stl` | `ddac21e79241514af47ac0e29fc37934777e8d087c4ccdec903e3c9aa95f4656` | `20260926-153429-joystick-j5-lift-0.5` |

Source 71c55b1. 10.4 × 10.4 × 5.1 mm. PETG, 0.16 mm, 4 walls, no supports,
no raft, flange down.

Check each one: the press-in click works with the cap on, all four
directions tilt without catching on the lid, and the cap stays on the stick.

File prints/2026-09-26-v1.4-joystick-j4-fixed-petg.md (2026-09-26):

# v1.4 J4 joystick, fixed socket — gray PETG

This is the reprint after the socket fix (9a2e611). The socket is identical
to J2's; the 7.4 mm flat-top half ball is unchanged. One copy, gray PETG from
bay 3, the same settings as the good J2 print.

Source 9a2e611, `stl/v1.4/joystick-j4-fixed.stl` (was `stl/v1.4/joystick.stl` until J5), SHA256
`b8290aae9c4e3f3a1d34156ae2c2e8b8ce44317bf4dc2e04f0218385a386a95c`.
10.4 × 10.4 × 5.1 mm. PETG, 0.16 mm, 4 walls, no supports, no raft,
flange down.

Sent to the HTTP inbox as `20260926-115734-joystick` with a GO. It replaces
the bad drop `20260926-112324-joystick`. Status: new. Print start
unconfirmed.

Check: the stick seats fully (3.0 mm socket), the press-in click, and tilt.

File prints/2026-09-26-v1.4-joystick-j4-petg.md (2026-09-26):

# v1.4 J4 joystick — gray PETG

Austin approves the 7.4 mm half-ball J4 ("that's what we want") and asks for
the joystick only. He gave no colour, so it uses gray PETG from bay 3, the
same as the last caps. It fits the existing v1.3 lid (same 8 mm hole) as
well as the v1.4 lid.

Source 5a98998, `stl/v1.4/joystick.stl`, SHA256
`657f9e9f6fc75517705cd6a755b3588075f9c89980d2ca11b1daf59f1fc5d626`.
10.4 × 10.4 × 5.1 mm. PETG, 0.16 mm, 4 walls, no supports, no raft,
flange down.

Sent to the HTTP inbox as `20260926-112324-joystick` with a GO (queue after
any running job). Status: new. Print start unconfirmed.

Check: the press-in click is easy to hit, the ball passes up through the lid
hole, and all four directions tilt freely.

## Result — FAILED, cause found

The print Mac printed 6× J4 + 12× v1.0 buttons in grey PETG (A3) on Austin's
direct request, finishing at 11:47. Austin: the J4 socket "doesn't work, it's
messy"; the J2 socket was much better (photos in `v1.4-photos/`).

Cause: a CAD error by Claude. J4 added a solid 7.4 mm sphere centred at
z 8.5. Its bottom reaches z 4.8, inside the stick socket (z 3.4–6.4), so the
union filled the top 1.5 mm of the 2 mm square. The socket was about 1.4 mm
deep instead of 3.0 (the void was 28.69 mm³ instead of 34.78). The check
"unchanged below the ball" started at z 4.8 and could not see this. The print
settings matched the good J2 print (grey PETG, A3, 4 walls). Fix in the next
commit: re-cut J2's exact socket after adding the ball, and check the socket
void against J2. The six printed J4 caps are scrap.

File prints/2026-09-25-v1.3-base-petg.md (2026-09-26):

# v1.3 base — black PETG

Austin asks for the v1.3 base next, assuming the v1.3 lid works. He gave no
colour, so it uses black PETG from AMS bay 1, the same as the earlier bases.
It mates only with the v1.3 lid.

Source ccf3351, `stl/v1.3/base-floor-down.stl`, SHA256
`c26d3ef5e49ccafc011539eb48be9c252d24a54c676e4136f60ca8a9ff83859e`.
33.04 × 58.60 × 18.67 mm. PETG, 0.16 mm, 4 walls, no supports, no raft,
floor down.

Sent to the HTTP inbox as `20260925-212040-base-floor-down` with a GO queued
after the white v1.3 lid. The message also marks the v1.1 base drop as
superseded; the inbox shows that drop on hold. Print start unconfirmed.

## Result (2026-09-26)

Printed and assembled with the white v1.3 lid. Austin: "This latest fix works
great. It holds the case just right. Nothing rattles around. Everything
clicks." v1.3 is promoted to current best in `stl/current/`.

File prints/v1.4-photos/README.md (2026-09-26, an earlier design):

# J4 socket failure photos — 2026-09-26

Austin's photos compare a good J2 joystick socket with a failed J4 socket
(IMG_0880, IMG_0881). The metadata is removed and the pixels are unchanged;
hashes are in the `.json` files. No dimension was taken from them.

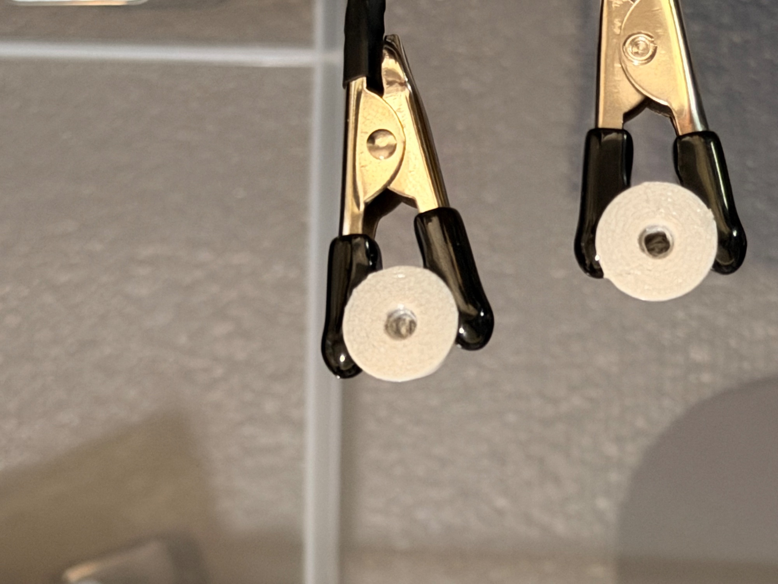
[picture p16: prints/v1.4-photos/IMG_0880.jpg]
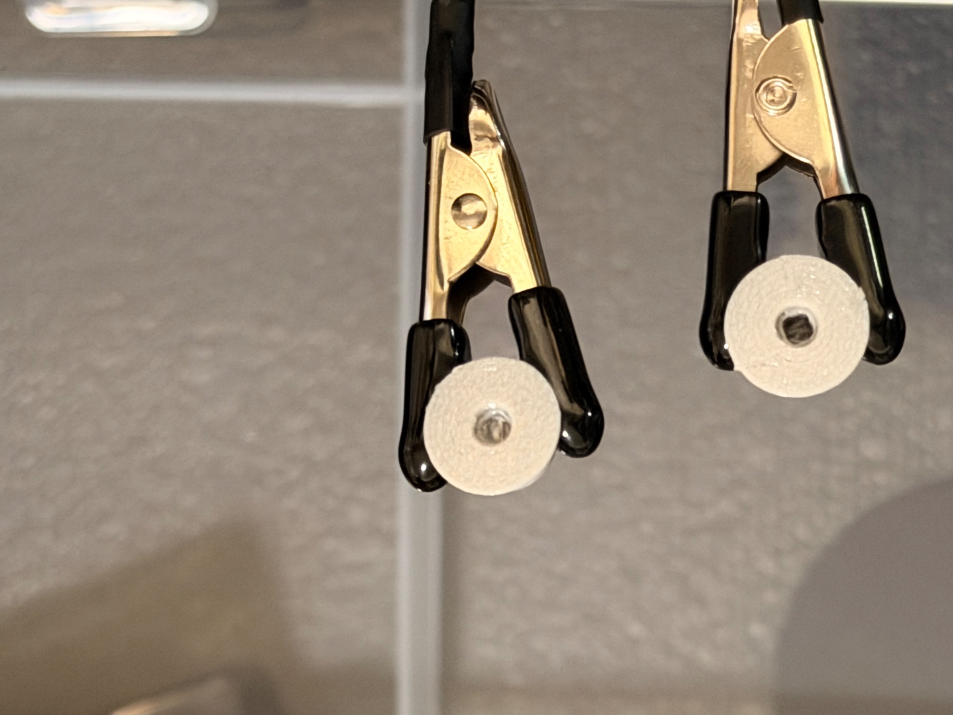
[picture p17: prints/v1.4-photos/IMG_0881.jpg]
 

Cause (found in CAD, see `../2026-09-26-v1.4-joystick-j4-petg.md`): the
bigger J4 ball sphere filled the top 1.5 mm of the 2 mm square socket.

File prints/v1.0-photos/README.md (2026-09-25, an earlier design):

# V1.0 photos — 2026-09-25

Austin took these photos of his own printed S2 case (S1 lid, S2 base and
buttons, J2 joystick) and sent them for the record. Metadata is removed and
the decoded pixels are unchanged. The hashes of the original and public files
are in each `.json` file, and the original uploads stay outside Git. No
dimension was taken from any photo.

| Photo | Shows |
|---|---|
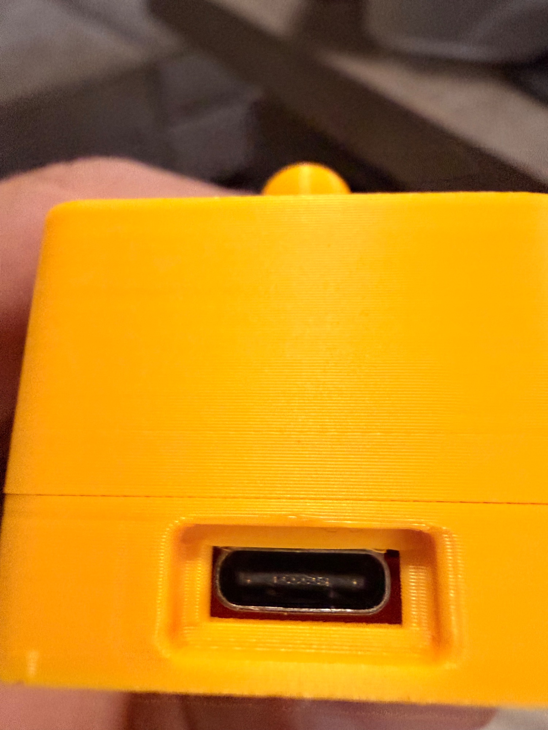
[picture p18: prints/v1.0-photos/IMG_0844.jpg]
|  IMG_0844 | USB-C end. The receptacle sits against the top of the opening, so V1.0 raises the opening 0.25 mm |
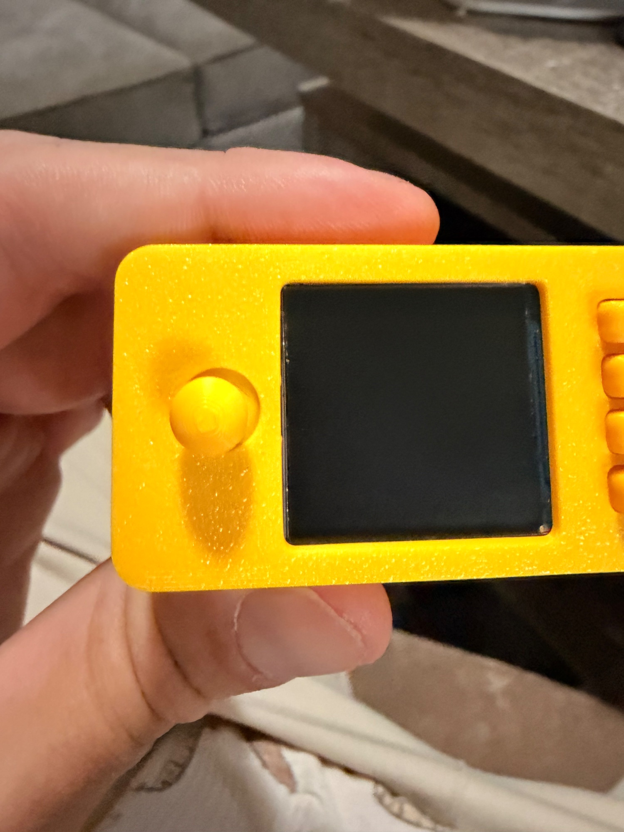
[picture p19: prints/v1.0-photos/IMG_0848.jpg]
|  IMG_0848 | Joystick close-up. The cap sits off-centre in its hole, so V1.0 moves the hole 0.25 mm away from the LCD |
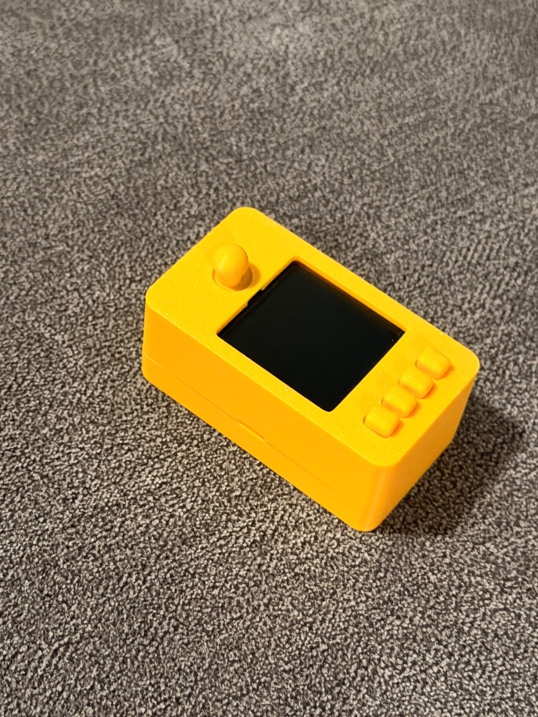
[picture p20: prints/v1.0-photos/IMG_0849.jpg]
|  IMG_0849 | Assembled case |
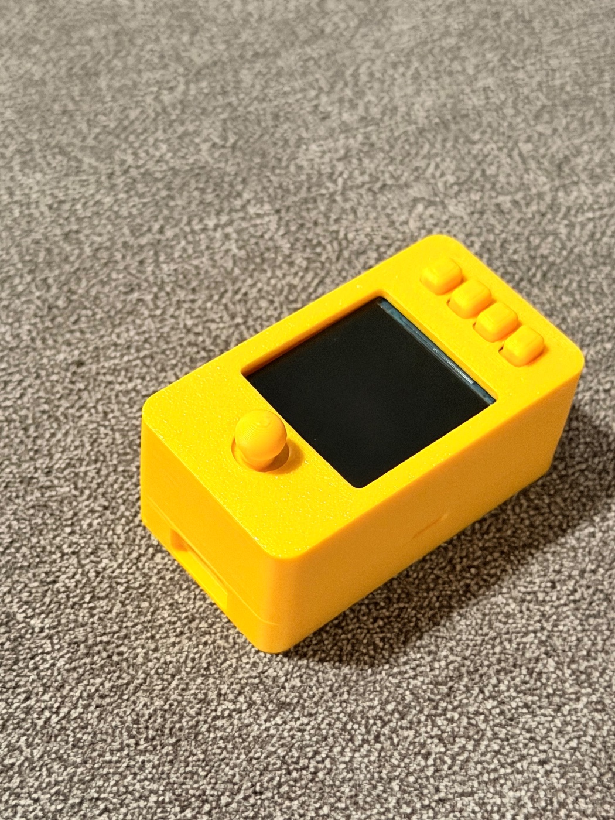
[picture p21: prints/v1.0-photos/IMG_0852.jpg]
|  IMG_0852 | Assembled case, other side |
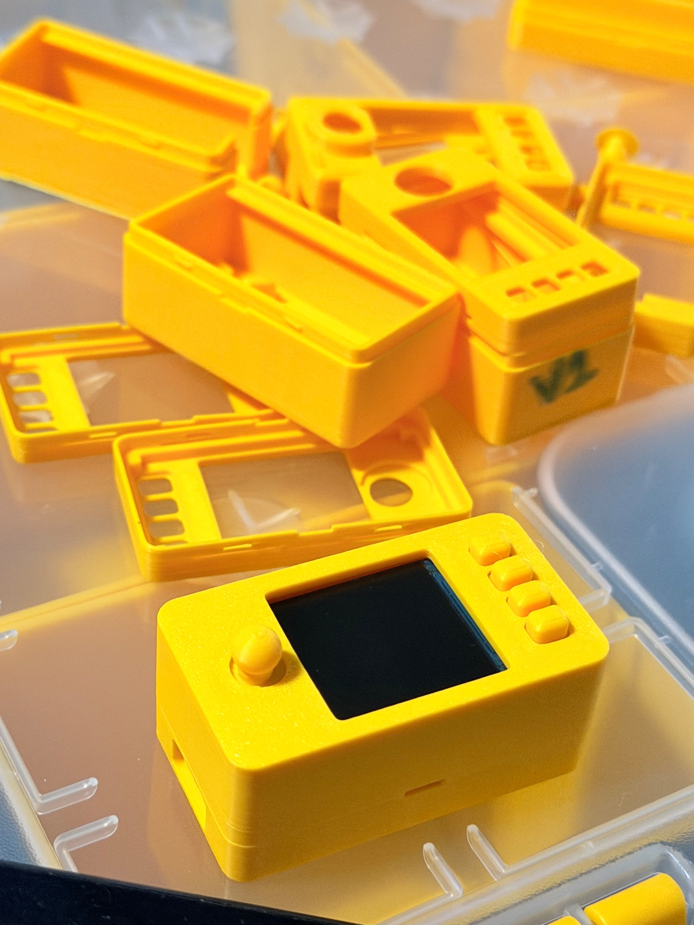
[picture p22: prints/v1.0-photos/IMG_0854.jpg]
|  IMG_0854 | The working case on top of the discarded prototypes it replaced |

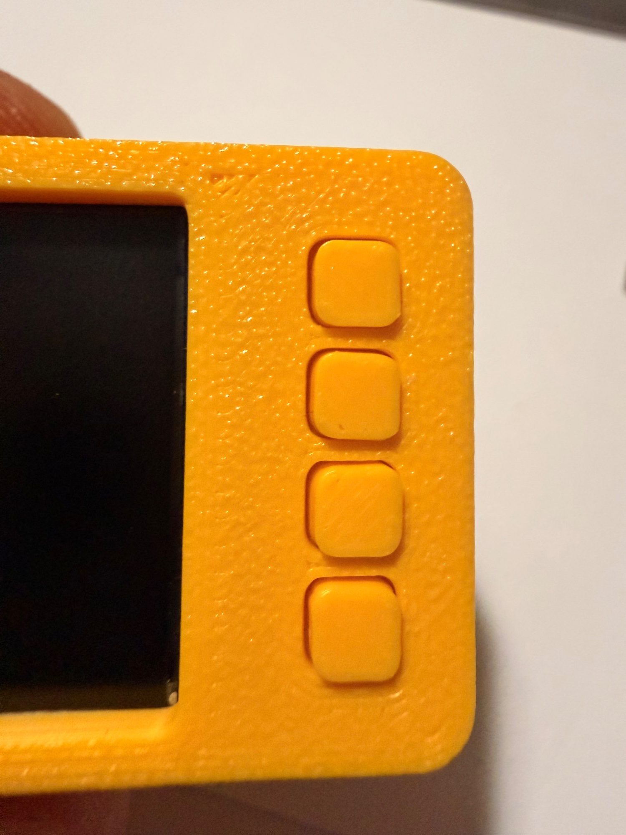
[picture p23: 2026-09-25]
prints/v1-feedback/IMG_0800.jpg

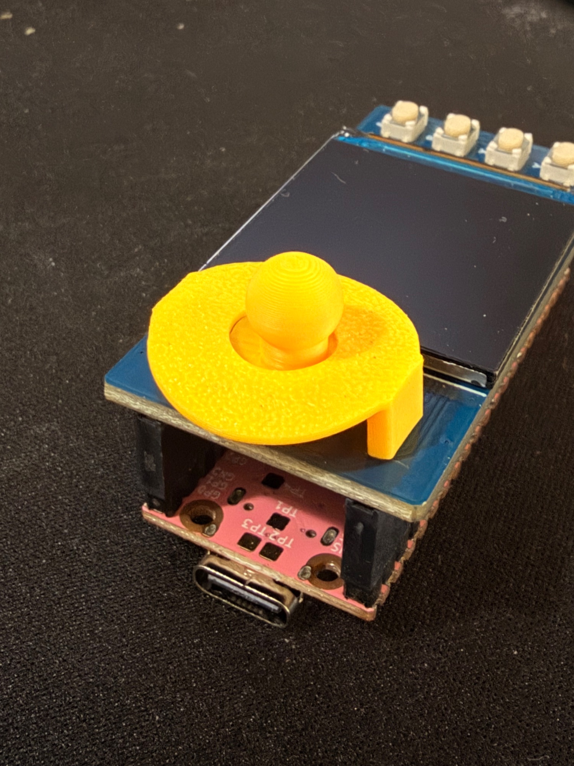
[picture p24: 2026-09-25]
prints/v3-photos/IMG_0814.jpg

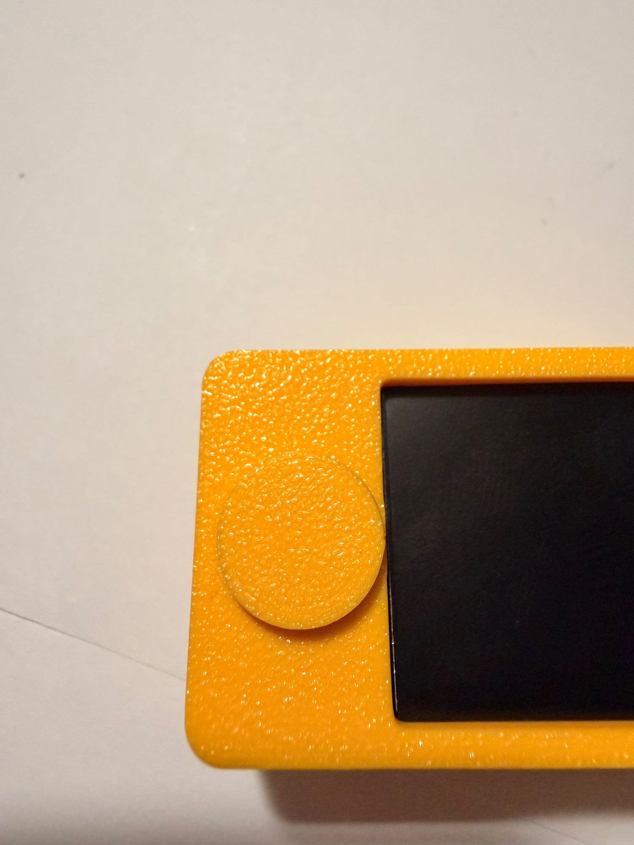
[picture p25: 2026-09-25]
prints/v1-feedback/IMG_0801.jpg

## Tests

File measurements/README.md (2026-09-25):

Caliper photos and datasheet drawing screenshots that back rows in
`../MEASUREMENTS.md`. Name files by row ID, e.g. `S1-glass-length.jpg`.
Current captures and their sources are indexed in LOG.md. Evidence limitations
discovered in R4 are recorded in MEASUREMENTS.md; some frames miss jaw contact.

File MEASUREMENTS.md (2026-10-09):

# Measurements

Every number the design uses lives here first. Rows have an ID. `cad/` cites
the ID. Blank means not measured yet. Units are mm.

Sources: `cal` = caliper on the bench, three readings, photo in
`measurements/` where useful. `ds` = datasheet or drawing, name the document
and page. When cal and ds disagree, write both and say which we use.

## Boards

There are several Pico-footprint boards on the bench and they differ: micro-USB
vs USB-C, connector overhang, component heights, sometimes hole positions. Each
board gets its own scan, its own caliper rows and its own photo set. The case
either fits all of them or has a base per board, decided in `DESIGN.md` once
the numbers are in.

Board register. Add a row when a new board shows up. The tag prefixes its rows
and files (`P2W-P11`, `measurements/P2W-P11-usb-overhang.jpg`).

| Tag | Board | USB | Marking / colour | Chip | Notes |
|---|---|---|---|---|---|
| P2W | Raspberry Pi Pico 2 W, official | micro-USB | green | RP2350 | official Pico 2 STEP applies |
| PINK | USB-C clone, pink | USB-C | pink | RP2040 | no CAD exists, measure everything |
| RP2040PLUS | Waveshare RP2040-Plus, with a battery | USB-C | blue | RP2040 | battery plug on the non-USB end, bottom face, centred. Only the plug is measured (BAT1) |
| | | | | | add more here |

## P. Pico-footprint board rows. One copy per board tag.

Datasheet values below are from the Raspberry Pi Pico 2 W datasheet, mechanical
drawing section, and apply to P2W only. Confirm each with calipers. Copy this
table once per tag; clones must not inherit the datasheet numbers.

| ID | Dimension | Value | Source | Notes |
|---|---|---|---|---|
| P1 | Board length | 51.0 | ds Pico 2 W | confirm cal |
| P2 | Board width | 21.0 | ds Pico 2 W | confirm cal |
| P3 | PCB thickness | 1.0 | ds Pico 2 W | confirm cal |
| P4 | Mounting hole diameter | 2.1 | ds Pico 2 W | confirm cal |
| P5 | Hole centre from short edge | 2.0 | ds Pico 2 W | both ends, confirm cal |
| P6 | Hole centre from long edge | 4.8 | ds Pico 2 W | both sides, confirm cal |
| P7 | Hole spacing along length | 47.0 | ds Pico 2 W | P1 minus 2×P5 |
| P8 | Hole spacing across width | 11.4 | ds Pico 2 W | P2 minus 2×P6 |
| P9 | Header pitch | 2.54 | ds Pico 2 W | |
| P10 | Header row spacing | 17.78 | ds Pico 2 W | 7 × 2.54 |
| P11 | Micro-USB overhang past board edge | | cal | |
| P12 | Micro-USB shell width | | cal | |
| P13 | Micro-USB shell height | | cal | |
| P14 | Micro-USB centre offset from board centreline | | cal / ds | |
| P15 | Height of tallest part above PCB, bottom side (component side facing away from LCD) | | cal | wireless module, BOOTSEL |
| P16 | BOOTSEL button position from short edge | | cal | |
| P17 | BOOTSEL button position from long edge | | cal | |
| P18 | Header pin length below PCB when plugged into LCD | | cal | how far the Pico sits from the LCD board |

| P19 | USB connector type | | look | micro-USB or USB-C |
| P20 | Mounting holes present and where | | cal / scan | clones sometimes move or drop them |
| P21 | Flatbed scan of the bottom side, 1200 dpi | | scan | `measurements/<TAG>-scan-bottom.png` |
| P22 | Flatbed scan of the top side, 1200 dpi | | scan | `measurements/<TAG>-scan-top.png` |

### P2W rows: (table above, fill in)

### PINK rows (USB-C clone, pink, RP2040, male headers soldered). All cal, none from a datasheet.

| ID | Dimension | Value | Source | Notes |
|---|---|---|---|---|
| PINK-P1 | Board length | 51.04 | cal 2026-09-24 | scan01 read 50.75 (edge blur); matches the official Pico outline. `measurements/2026-09-24-cal-PINK-P1-board-length-1.jpg` |
| PINK-P2 | Board width | 20.82 | cal 2026-09-24 | scan01 read 20.95 (edge blur). `measurements/2026-09-24-cal-PINK-P2-board-width-1.jpg` |
| PINK-P3 | PCB thickness | 1.23 | cal 2026-09-24 | `measurements/2026-09-24-cal-PINK-P3-pcb-thickness-1.jpg` |
| PINK-P11 | USB-C overhang past board edge | 2.47 | scan01 | shell past the short edge; the scan edge was sharp here (shell sits on the glass). ±0.2 |
| PINK-P12 | USB-C shell width | 8.87 | cal 2026-09-24 | metal shell, wide way. `measurements/2026-09-24-cal-PINK-P12-usbc-width-1.jpg` |
| PINK-P13 | USB-C shell height | 3.08 | cal 2026-09-24 | metal shell, thin way. Shell top is ~2.4 above the PCB (A1), so ~0.7 of it sits in/below the board line. `measurements/2026-09-24-cal-PINK-P13-usbc-height-1.jpg` |
| PINK-P15 | Tallest part above PCB, component side | 3.25 | cal 2026-09-24 | Austin read 4.48 PCB back face to USB-C shell top = the board's full thickness; minus PINK-P3 1.23. Stack check: A1 19.95 − 17.54 = 2.4 (jaws not exactly opposite there); use 3.25. `measurements/2026-09-24-cal-PINK-P15-board-plus-usbc-height-1.jpg` |
| PINK-P18 | Header pin length below PCB | ~10.0 | cal 2026-09-24 | Austin: 10.5 jaw to jaw including the solder tips on the top face; about 10.0 from the underside to the pin tips. The stack (A rows) is the number that matters. `measurements/2026-09-24-cal-PINK-P18-pin-length-1.jpg` |
| PINK-P18b | Header plastic strip thickness | | cal | |
| PINK-P19 | USB connector type | USB-C | look | |

## L. Waveshare Pico-LCD-1.3, board

| ID | Dimension | Value | Source | Notes |
|---|---|---|---|---|
| L1 | Board length | | cal / ds Waveshare drawing | |
| L2 | Board width | | cal / ds | |
| L3 | PCB thickness | 1.97 | cal 2026-09-24 | one reading, `measurements/2026-09-24-cal-L3-lcd-pcb-thickness-1.jpg` |
| L4 | Corner radius of PCB | | cal | |
| L5 | Mounting hole diameter | | cal / ds | |
| L6 | Mounting hole positions, each, from one chosen corner | | cal / ds | list all |
| L7 | Female header socket height above PCB, Pico side | 8.69 | cal 2026-09-24 | sets stack gap. Read 10.66 socket top to PCB front face, minus L3 1.97. `measurements/2026-09-24-cal-L7-lcd-socket-height-1.jpg` |
| L8 | Female header position from edges | | cal / ds | |
| L9 | Tallest part on the Pico side other than headers | | cal | |

### Scan 01 results, LCD top side (2026-09-24). Source `scan01` = `measurements/2026-09-24-scan-01-all-boards-600dpi.jpg`, fit in `2026-09-24-scan-01-analysis.json`, overlay `2026-09-24-scan-01-lcd-top-fit.png`, code `tools/measure_scan.py`

Scale 23.666 px/mm from 196 rule ticks over 196 mm, fit RMS 0.73 px (0.031 mm); nominal 600 dpi would be 23.622. Origin: see "Chosen corner" below. Outline edges are blurred where the board sits off the glass, so outline rows carry ±0.3 mm until calipers confirm; centres of features that touched the glass (plungers, stem, glass) are good to ~0.1 mm.

| ID | Dimension | Value | Source | Notes |
|---|---|---|---|---|
| L1 | Board length (y) | 52.5 | cal 2026-09-24 | scan01 read 52.68 (edge blur +0.18). `measurements/2026-09-24-cal-L1-lcd-board-length-1.jpg` |
| L2 | Board width (x) | 26.44 | cal 2026-09-24 | scan01 read 26.58 (edge blur +0.14). `measurements/2026-09-24-cal-L2-lcd-board-width-1.jpg` |
| S1 | Glass outline length (y) | 26.48 | scan01 | black glass as visible; ±0.2 |
| S2 | Glass outline width (x) | 25.19 | scan01 | ±0.2 |
| S4 | Glass centre x | 13.15 | scan01 | glass spans x 0.56 to 25.75 |
| S5 | Glass centre y | 26.05 | scan01 | glass spans y 12.81 to 39.29 |
| B4 | Plunger diameter | 2.38 × 3.00 | cal 2026-09-24 | oval: 2.38 across x, 3.00 along y. Cap bears on top; the casing (B1/B2) is what the cap must cover. `measurements/2026-09-24-cal-B4-lcd-plunger-long-1.jpg` |
| B8a | Button Y centre (leftmost) x, y | 4.85, 4.14 | scan01 | |
| B8b | Button X centre x, y | 10.58, 4.00 | scan01 | |
| B8c | Button B centre x, y | 16.16, 4.02 | scan01 | |
| B8d | Button A centre (rightmost) x, y | 21.87, 4.12 | scan01 | |
| B8p | Button pitch (labels Y X B A left to right, from the silkscreen in `2026-09-24-cal-B2-lcd-button-body-1.jpg`) | 5.67 | scan01 | mean of the three gaps |
| J4 | Stem diameter at top | 2.41 | scan01 | dark cap only, confirm cal |
| J10 | Joystick centre x, y | 13.24, 46.22 | scan01 | stem top; base centre agrees within 0.4 |
| J1/J2 | Joystick base plan size | 8.81 × 7.22 | scan01 | fitted to the silver diamond, blurred; confirm cal |

Not from this scan: every Z (L3, L7, L9, S3, B3, B5, B6, J3, J6-J9), hole rows L5/L6 (none visible from the top; back side scan was out of focus), and the switch bodies B1/B2 (blurred).

## S. Screen

| ID | Dimension | Value | Source | Notes |
|---|---|---|---|---|
| S1 | Glass outline length | | cal | |
| S2 | Glass outline width | | cal | |
| S3 | Glass top height above PCB | 2.05 | cal 2026-09-24 | read 12.71 socket top to glass top, minus L3+L7 10.66. Whole hat, socket top to glass top = 12.71. `measurements/2026-09-24-cal-S3-lcd-glass-height-1.jpg` |
| S4 | Glass position from chosen corner, x | | cal | |
| S5 | Glass position from chosen corner, y | | cal | |
| S6 | Active area length | | cal / ds | |
| S7 | Active area width | | cal / ds | |
| S8 | Active area offset within glass, x | | cal | |
| S9 | Active area offset within glass, y | | cal | |
| S10 | Flex cable location and width | | cal | so the lid does not pinch it |
| F1 | Blue tape past the right PCB edge | ~4.0 out, y 22 to 30, at glass level | scan01 | soft edges. In the scan it lies on top of the glass and runs off the edge: probably the screen protector's pull tab, not part of the board. Ask Austin |

## B. Buttons, four tact switches

Measure the switch, not a cap. Identify the part if you can from the marking or
the schematic and add its datasheet to `SOURCES.md`.

| ID | Dimension | Value | Source | Notes |
|---|---|---|---|---|
| B1 | Switch body length | 3.34 | cal 2026-09-24 | metal casing, measured in y (toward the glass). `measurements/2026-09-24-cal-B1-lcd-button-body-1.jpg` |
| B2 | Switch body width | 4.42, 4.30 | cal 2026-09-24 | metal casing, two readings (feet may add to the first); the other plan axis from B1. `measurements/2026-09-24-cal-B2-lcd-button-body-{1,2}.jpg` |
| B3 | Switch body height above PCB | 1.81 | cal 2026-09-24 | Austin read 12.47 socket top to metal casing top, minus 10.66. Oval top (B5 2.61) is 0.80 proud of the casing. `measurements/2026-09-24-cal-B3-lcd-button-casing-height-1.jpg` |
| B4 | Plunger diameter | | cal | |
| B5 | Plunger top height above PCB, at rest | 2.61 | cal 2026-09-24 | Austin read 13.27 socket top to button top, minus L3+L7 10.66. `measurements/2026-09-24-cal-B5-lcd-button-height-1.jpg` |
| B6 | Plunger travel | 0.38 | cal 2026-09-24 | Austin read 12.89 socket top to oval held pressed = 2.23 above PCB; rest is 2.61. `measurements/2026-09-24-cal-B6-lcd-button-pressed-1.jpg` |
| B7 | Plunger shape | oval | look 2026-09-24 | light-coloured oval top; 2.38 across the narrow way (cal), about 2.6 long (scan01) |
| B8 | Centre of each switch from chosen corner, x, y | | cal / ds | four rows, name them by silkscreen label |
| B9 | Actuation force | | ds | for cap weight and return |

## J. Joystick

| ID | Dimension | Value | Source | Notes |
|---|---|---|---|---|
| J1 | Body length | | cal | |
| J2 | Body width | | cal | |
| J3 | Body height above PCB | | cal | |
| J4 | Stem diameter at top | 1.86 | cal 2026-09-24 | across the flats; square section. A cap grips this. A short lip at the very base is 2.94 wide (J4b, cal) — not part of the stick, the cap must clear it |
| J4b | Lip at the stem base, width | 2.94 | cal 2026-09-24 | no photo saved |
| J5 | Stem shape | square | look 2026-09-24 | 1.86 square at the tip, wider at the base |
| J6 | Stem top height above PCB, centred | 5.00 | cal 2026-09-24 | Austin read 15.66 socket top to stem tip, minus L3+L7 10.66. `measurements/2026-09-24-cal-J6-lcd-joystick-height-1.jpg` |
| J7 | Stem tilt angle, full deflection | | cal / ds | |
| J8 | Stem top travel at full deflection, horizontal | | cal | |
| J9 | Centre press travel | | cal / ds | |
| J10 | Centre from chosen corner, x, y | | cal / ds | |
| J11 | Clearance around stem before it hits the body or nearby parts | | cal | |

## A. Assembled stack

| ID | Dimension | Value | Source | Notes |
|---|---|---|---|---|
One block per board tag. The hat is the same; the Pico under it changes.

| ID | Dimension | Value | Source | Notes |
|---|---|---|---|---|
| A1 | Total stack height, Pico bottom-most part to glass top | PINK: 19.95 (glass to USB-C shell); 17.54 glass to the Pico PCB back face | cal 2026-09-24 | Austin: 19.95 is "very close" — jaws not exactly opposite because the plug and glass are at different spots; take as ±0.2. So the USB-C shell stands ~2.4 above the Pico PCB. `measurements/2026-09-24-cal-PINK-A1-stack-glass-to-usbc-1.jpg`, `...-pcb-back-{1,2}.jpg` |
| A2 | Gap between Pico PCB top and LCD PCB bottom | PINK: 12.29 | derived 2026-09-24 | 17.54 − S3 2.05 − L3 1.97 − PINK-P3 1.23. Socket is 8.69 of that; the male header plastic + standoff is the other 3.6 |
| A3 | Pico USB position relative to LCD board edges | joystick end, centred in x (assumed) | Austin 2026-09-24 | USB-C pokes out at the joystick end. x-centring not measured yet |
| A4 | Anything sticking out past the LCD board outline | | look | per tag |

## T. Print tolerances, filled in during Phase 3

| ID | Dimension | Value | Source | Notes |
|---|---|---|---|---|
| T1 | Hole clearance for a free fit | | print | |
| T2 | Clearance for a snug slide | | print | |
| T3 | Cap-to-hole radial clearance | | print | |
| T4 | Printer and nozzle | | | |
| T5 | Material | | | |

## Chosen corner

State here which corner of the LCD board is the origin for all x, y values,
looking at the screen, and which direction is +x and +y. Use the same origin in
`cad/params.py`.

Origin (chosen 2026-09-24): looking at the screen with the joystick at the top
and the four buttons at the bottom, the FPC tape is on the right. Origin is
the bottom-left corner of the LCD PCB. +x to the right (26.44 wide), +y up
toward the joystick (52.50 long, after calipers). The 600 dpi scan is not mirrored (the
rule's digits and the Pico's silkscreen read correctly), so scan x, y map
straight onto this frame.

## R4 audit: derived coordinates and evidence limits

The scan's absolute corner coordinates above used its blurred 26.5835 ×
52.6773 outline. CAD preserves offsets from the fitted board centre and
uses the caliper outline. These are a registration assumption, not new
caliper readings. Do not scale feature spacing to fit the caliper outline.

| ID | Dimension | Value | Source / limitation |
|---|---|---|---|
| SC1 | Glass centre offset x, y | -0.1393, -0.2905 | scan01 JSON glass_centre_uv, reordered v,u |
| BC1 | Button centre offsets x, y, Y/X/B/A | (-8.4400,-22.1949), (-2.7159,-22.3382), (2.8723,-22.3153), (8.5746,-22.2187) | scan01 plungers_uv, reordered v,u; retain individual y values |
| JC1 | Stem centre offset x, y | -0.0529, 19.8792 | scan01 joystick_stem_uv |
| JC2 | Silver base centre offset x, y | 0.2730, 19.4936 | scan01 joystick_base_centre_uv; blurred; differs from stem by 0.505 mm |
| H1 | Header body width/length | 2.54 / 50.8 | provisional render envelope from P9 × 1 / 20; actual plastic and solder envelope unmeasured |
| H2 | Pico corner radius / USB inward depth | 1.0 / 7.0 | inherited render assumptions, not measurements |
| H3 | Silver base orientation / height | 45 degrees / 3.0 | inherited render assumptions, not measurements |
| H4 | PCB corner radius | 1.5 | inherited render only; collision checks also use a sharp rectangle |
| H5 | Blue flag thickness / inboard overlap | 0.3 / 1.0 | inherited illustrative envelope; identity unresolved |

Photo audit: L3's frame shows no board or caliper; S3 and B6 miss the
measurement contact; L7's frame is not a reliable picture of the recorded
10.66 datum. B4's display appears 3.06 rather than recorded 3.00; B2's second
display appears 4.31 rather than 4.30. A1 photos do not unambiguously show
glass contact, so A2 inherits a datum uncertainty as well as the known USB
0.84 discrepancy. PINK-P11 comes from a segmentation that also reports a
20.95-mm USB width (inconsistent with P12 8.87); its ±0.2 claim is not
independently established. Retain all original readings pending recheck.

### R4 design choices (not hardware measurements)

| ID | Choices in mm unless stated | Rationale |
|---|---|---|
| D4-FIT | mating gap 0.20; skirt 0.80; wall 2.20; bump 0.45 × 4 × 1; flexible band span 14; slot 0.60; band roof z=-0.30 | maintain 1.20 tongue; outward flex/release access; bands anchored at both ends to bridge when printed inverted |
| D4-SUPPORT | shelf bearing thickness 0.80, 45-degree underside; pad 1.60, inset 0.50, gap 0.05; shelf gap 0; pocket radius 0.50 | slope from wall to shelf tip; four pads land above side shelves outside switches; sharp corner sensitivity |
| D4-BUTTON | flange 5.00; pocket margin 0.30 | avoid neighbouring flanges colliding when each cap slides sideways by 0.25; no overtravel stop until casing and PCB landing areas are confirmed |
| D4-USB | channel clearance 0.25 for lid fin; shell opening square corners; inherited plug trial 12.5 × 7, recess 1.0 | square envelope contains both rectangular shell bounds; insertion straight down |
| D4-JOY | socket total clearance 0.05 (samples 0, 0.10, 0.20); tip clearance 0; engagement 1.20; disc gap 1.80; hole 12.80; disc 14.0 | seat cap on stem, improve tilt/press room over assumed body and base offset clearance; fit samples are provisional |
| D4-CAD | boolean overlap 0.01; cutter extension 1; bump overlap 0.20; window end clearance 0.30; cavity radius 0.50; window/pocket radius 0.80; plug recess radius 1.0 | construction choices, not hardware facts |
| V4 | joystick sensitivity 10 degrees tilt, 0.30 press, pivot z=0 and 3; XY placement sensitivity 0.10; cap travel sampling 9 positions; insertion sampling 1 mm | diagnostic scenarios only; J7/J9 remain unmeasured |

## R5 user feedback and original choices

Austin reports from the first physical print: joystick must be installed on
the board before the lid and retained by a lower lip; upper control should
be shaft and ball. Also requests a pry notch because the case is hard to
open. No new hardware dimensions supplied. Existing J rows still apply.

| ID | Choices in mm unless stated | Rationale |
|---|---|---|
| D5-JOY | shaft Ø4.20; retaining flange Ø10.40, bottom z=5.00, thickness 0.80; ball Ø7.00, centre z=11.40; throat Ø8.80; flange pocket Ø13.00, ceiling z=6.80; collar outside Ø15.80, roof 1.20 | ball passes opening from inside while wider lip is retained; raised collar clears lip's assumed tilt; socket and engagement inherited from R4 |
| D5-PRY | two side notches centred at y=L1/2, width 6.0 along y, height 1.60, depth 1.0 from exterior, radius 0.50; z centre=-TONGUE_H | gives tool access across skirt/base seam; retains 1.20 of wall behind notch, away from boards |
| V5 | sample press 0 and 0.30, pivots 0 and 3, tilt 0/5/10 degrees; cap pull-up 1.05; assembly clearance with vertical swept envelopes; tool tip 4.0 × 0.60, depth 0.70 | test scenarios, not measured joystick specs or opening-force guarantees |

### V2 print candidate / R5 completed choices

### V3 review choices — 2026-09-25

### V3 low-lid experiment — D7, 2026-09-25

### D8 rear-tab experiment

### J1 isolated round-lip test — 2026-09-25

### V3-FIT fitted shell — 2026-09-25

### V3-FLAT correction — 2026-09-25

### J2 stepped socket trial — 2026-09-25

| ID | Value | Source / limitation |
|---|---|---|
| J2-COLLAR-H | less than1 mm | Austin's direct report after asking collar-only height; not PCB-to-collar height |
| J2-SOCKET | Ø3.00 round opening depth1.00, then2.01 square depth2.00; total3.00 from cap underside | Austin's explicit trial dimensions; square width inherited J1. No extra clearance. IMG_0823 shows3.32 mm on caliper but feature unconfirmed; fit not guaranteed |
| J2-OUTER | identical J1 exterior; blind roof becomes localz3.00 instead of1.90; possible1.10 deeper seating if collar/body allow | Original derived geometry, not measured achievable travel. Do not lower lid until fitted; print flange-down as J1 |

### V3-FLAT parameters

| ID | Choice | Basis |
|---|---|---|
| V3-FLAT | uniform outer facez5.1; underside joystick roof4.4 unchanged; face-down print, rotate180degrees aroundX then translate bedz0; no supports/raft | Austin explicitly approves whole-face raise to fix print orientation. Existing J1 clearance, not new hardware measurement. Screen depth3.05 mm accepted provisionally; unchanged V2 button protrusion1.3 mm, .92 at full press |

### V3-FIT parameters (historical upright print)

| ID | Original design choice | Basis / limitation |
|---|---|---|
| V3-FIT-LID | screen side rails z3.05, local joystick roof4.4..5.1, holeØ8, pocketØ13, outer local bossØ15.8 clipped at screen window; inner pocket clipped window+.4, continuous .4 front wall; button-end top4.6, region ends pocketYmax+.8 | Retain J1's hand-held tested hole/height and V2 buttons; no universal lid-height raise. Local joystick front wall meets upper screen edge, so that small edge segment is higher than side rails. Boss shell dimensions inherited D5/D6; upright print to avoid floating skirt under face-down boss |
| V3-FIT-BUTTON | existing flange z2.61..3.41, pocket ceiling3.56, tops6.4, original4.2×5.4 posts | Exact V2 printed cap parameters; no new caps. V3 low D7 side-wing caps were never printed and must NOT be used |
| V3-FIT-PADS | extend original1.6 square corner pads outward to inner walls, top2.36, bottom.05 | Join pads to shell from first printed pad layer; small corner overhangs still require slicer review |
| V3-FIT-PRINT | both shells upright, bedz0, separation5; PLA .16,3 walls, no supports/raft | Original print plan; actual slice must be checked before start. Lid bottom skirt supplies bed contact, not the raised joystick face |
| V3-FIT-CHECK | inherited0/5/10degree, pivots0/3, press0/.3,8directions; lid-install lifts0..12 in .5 increments; seating shifts0/-.3; mesh tolerance.02/angular.1 | Hypotheses not hardware measurements; compare against J1 to prevent hiding new interference. Additional guessed-body contact reported separately |

### J1 isolated round-lip test parameters

| ID | Choice (mm) | Source / limitation |
|---|---|---|
| J1-CAP | socket 2.01 square, roof5.30, neck Ø5, bottom3.40; flange Ø10.4 × .4 at3.40; ball Ø7 centre8.5 | Original D6-SOCKET baseline; flange and shorter ball are original trial choices, not measurements |
| J1-LID | round hole Ø8, outer disk Ø20, underside4.4, thickness.7; two feet x=±9, width2, y length6, PCB contactz0 | Original hand-held test gauge, not production lid. Local top5.1 =3.05 above glass; surrounding production lid remains undecided. Feet establish height on bare PCB beside joystick; fit needs checking |
| J1-CHECK | tilt0/5/10 degrees; pivotsz0/3; press0/.3; eight compass directions | Stress scenarios only, not measured travel. Preserve failures in report. Print mesh tolerance .02, angular .1; separation5 on plate |
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

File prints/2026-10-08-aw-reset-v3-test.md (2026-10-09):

# RESET v3 test caps

RESET v2 made 0.60 (1 notch), 0.75 (2 notches), 0.90 (3 notches) shorter.
2 copies each, flange down, PETG 0.16, 4 walls, no supports, brim or raft.
Drops `20261008-215129-reset-v3-1-notch`, `20261008-215130-reset-v3-2-notch`,
`20261008-215131-reset-v3-3-notch`. Files in `stl/test/aw-reset-v3/`.

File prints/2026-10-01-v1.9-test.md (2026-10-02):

# V1.9 TEST lid (not the current version)

The +0.3 lid with (1) the bezel brought back down to 0.3 above the glass (it
was 1.1: the screen gap) and (2) the briefs logo inlaid under the joystick.

Two files, same coordinates, loaded as one object: the lid in the lid
filament, the logo part in a second filament for its first 2 layers.
Drops `20261001-220934-lid-v1.9-test-face-down` (SHA256 `68807a74…`),
`20261001-220934-logo-inlay-face-down` (SHA256 `38d461a5…`). No colour or GO.
PETG 0.16, 4 walls, face down, no supports, raft or brim.

Check: the logo reads; the bezel sits close to the glass without touching it;
the lid still closes on a v1.7 base with J22.

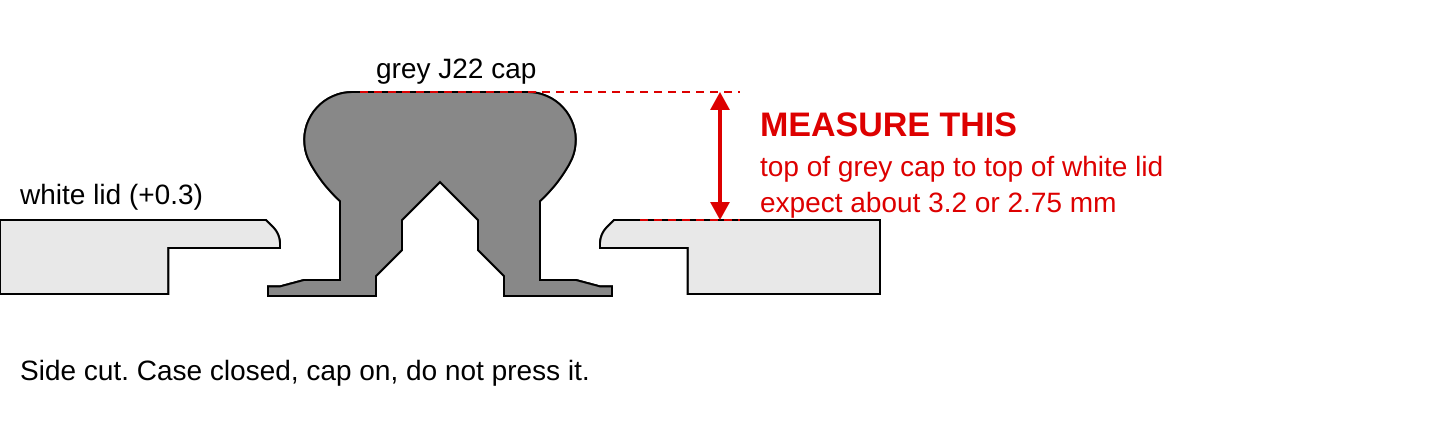
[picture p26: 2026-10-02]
renders/plan/measure-cap-height.png

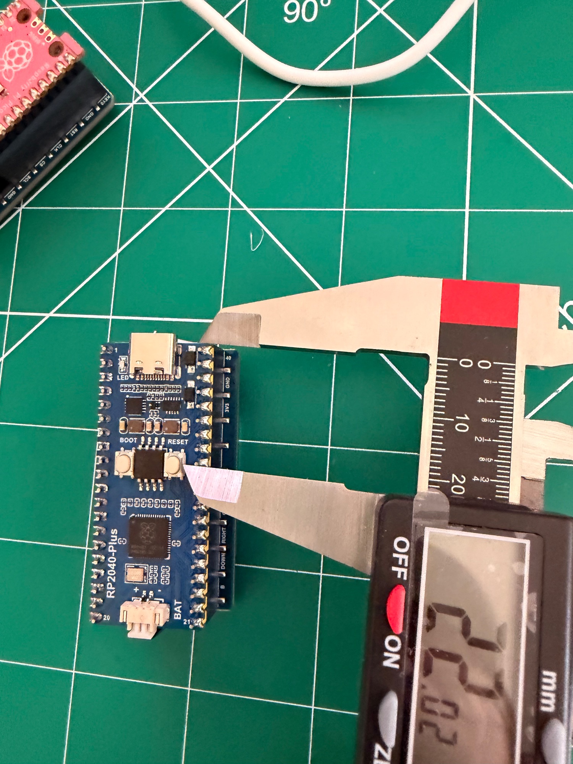
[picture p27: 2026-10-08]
measurements/2026-10-08-cal-RP2040PLUS-button-from-usb-end-1.jpg

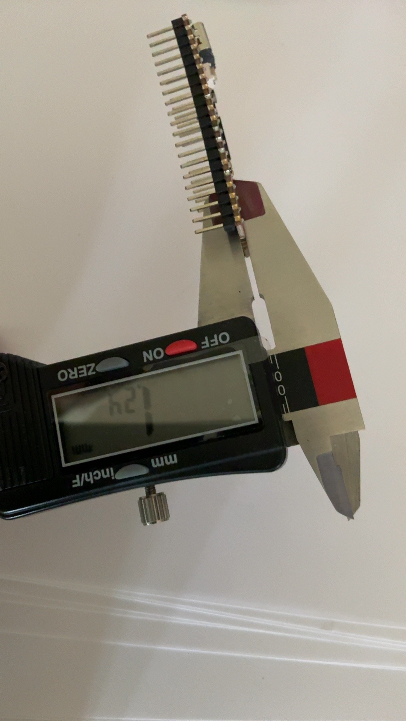
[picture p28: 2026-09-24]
measurements/2026-09-24-cal-PINK-P3-pcb-thickness-1.jpg

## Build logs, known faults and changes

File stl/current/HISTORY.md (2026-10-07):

# stl/current change log

2026-10-02: Austin tested J24-A in the V1.9 test lid (+0.3) with S2 buttons:
holds against a hard pull, diagonals don't click centre, centre clicks
cleanly, screen gap right: "everything is good". The v1.9 lid is that test
lid without the logo. Base unchanged (v1.7). J24-A also seemed fine in an old
v1.7 lid on a quick try; the v1.9 lid gives it 0.3 more room. These paths never change: when a newer version wins
a physical test, `cad/current.py` replaces the files and `current.json`.

| File | Part | From | Per case |
|---|---|---|---|
| `lid.stl` | Lid, face down: v1.7 0.3 taller inside, bezel back down to 0.3 over the screen, no logo | v1.9 | 1 |
| `base.stl` | Base, floor down: 6 locking catches, pry slot | v1.7 | 1 |
| `joystick.stl` | J24-A joystick: J22's flat-top 7.4 ball, round 10.0 flange (thin 0.24 edge, no tabs), hole 1.9 deep: round 3.1 for 0.35, then the 1.90 square | J24-A | 1 |
| `button.stl` | Button cap, flange down | v1.0/S2 | 4 |
| `full-set.stl` | All seven on one plate | — | — |

PETG, 0.16 mm, 4 walls, no supports, no raft, no brim (caps can't be removed
from a brim or raft). Lid: elephant-foot compensation 0.15. For N copies, use the slicer's
copies setting (or `copies=N` on the print inbox).

Austin tested this set on 2026-09-26 and said "everything works fine". The
v1.5 lid is the only new part. On 2026-09-30 the joystick became J14-2: no
centre click on direction pushes, the cleanest centre press, and it stays on
the stick best. It fits the v1.5-v1.7 lids (same roof under the joystick).

The v1.7 lid and base are what Austin batch-prints (print Mac, 2026-09-30):
lid drop `20260927-115641-lid-face-down`, 24 in white PETG; base drop
`20260927-112055-base-floor-down`, 24 (12 black, 12 grey); four plates of six
each, 2026-09-27 to 29. The v1.5 lid / v1.3 base listed here until today
were stale: v1.7 was never written back after it passed. The bases and buttons are the ones already
printed. Hashes and sources are in `current.json`.

Stable links:
`https://raw.githubusercontent.com/clawdbotatg/clawd-pico-case/main/stl/current/<file>`

## On the print Mac

v1.5 reference drops (2026-09-26, not printed): `20260926-213136-lid`, `20260926-213137-base`, `20260926-213137-joystick`, `20260926-213137-button`, `20260926-213138-full-set`.
A message tells the print Claude to reprint them on request with `copies=N`,
and that they replace the v1.3 CURRENT drops.

J22 joystick drop (2026-09-30, no raft, copies on request): `20260930-211620-joystick` (replaces the J15 drop `20260930-122840-joystick`).

On 2026-09-30 evening the joystick became J22 (J21-1 with a flat top): the
wide mouth clears the stick's collar so a press clicks only the centre, the
tabs are meant to keep it in the lid, and 1.9 deep is the depth Austin picked.

Known limits (V1.8-FEEDBACK, 2026-10-01): J22 sometimes clicks N + W + centre
on a NW push, and a hard push or pull can take it out of the case. The +0.3
test lid is better but not fixed. It is current because it is the best tested,
not because it meets these requirements. See `JOYSTICK-PLAN-2026-10-02.md`.

v1.9 drops (2026-10-02, copies on request): lid `20261002-145626-lid`, joystick `20261002-145627-joystick` (J24-A; replaces J22's `20260930-211620-joystick`). Base stays v1.7 `20260927-112055-base-floor-down`.

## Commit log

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2026-09-24 CAD: hat, Pico, first snap-fit case, caps; browser viewer
    cad/params.py cites a MEASUREMENTS.md row per number; the four guesses
    (Pico centred, USB end, L4, J3) are named there and in the viewer.
    build.py exports STLs and a self-contained three.js viewer. Design
    decisions (snap fit, PINK only, Bambu P2S) in DESIGN.md. Pre-commit
    hook: gitleaks + address/hostname/email grep.
    [base.stl, button_caps.stl, hat.stl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]
2026-09-25 Caps: square, flanged under the lid, 1.0 mm webs between the holes
    [button_caps.stl, joystick_cap.stl, lid.stl]
2026-09-25 Build: print-oriented STLs in stl/print (lid and joystick cap flipped)
    [base.stl, button_caps.stl, joystick_cap.stl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]
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2026-09-25 Report: every measurement, the design, decisions, confidence, asks
    Crypto board removed from the model and docs (not a case input). FPC tape
    added to the mock-up. assembly.step exported.
    [assembly.step, fpc_tape.stl]
2026-09-25 Audit: fix snap (windows + wedge bumps), pocket corners, params; provenance, design, readme, report
    [assembly.step, base.stl, lid.stl]
2026-09-25 Test 2 best guess: 12 mm joystick hole, neck+disc joystick cap, taller USB slot, plug recess, lid hold-down pads
    [assembly.step, base.stl, joystick_cap.stl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]
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2026-09-25 R4: correct enclosure assembly and control clearances; preserve validated prototype
    Add mating clearance and flexible latch bands, a USB insertion channel and lid fin, sloped board shelves and four hold-down contacts. Correct displaced joystick-body and individual button positions; prevent neighbouring cap flange collisions; provide joystick socket fit samples.
    Preserve original measured inputs and document unresolved hardware assumptions. Include source/output hashes, CAD preview and 171 passing geometric checks. Print and sample STL meshes independently checked for closed edges and bed placement. Physical fit remains unverified; test 3 is prepared, not started.
    [assembly.step, base.stl, button_caps.stl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]
2026-09-25 Print log: pin R4 to saved prototype tag and record dispatch preflight
    Record print-Mac authentication failure and occupied plate observed by camera. R4 has not been sliced, uploaded or started; actual AMS material remains unverified.
2026-09-25 Print R4: submit four verified models to HTTP inbox and record request IDs
    Request one plate after the current job and clearance, PLA at 0.16 mm. Record checksums, sizes, orientations and pending status. Correct the mistaken SSH prerequisite; printer start remains unconfirmed.
2026-09-25 Save V1 photo feedback and R5 captive joystick/pry-notch checkpoint
    Preserve intermediate geometry and 273 checks. USB, rectangular buttons and board-button access remain pending; do not print this checkpoint.
    [assembly.step, base.stl, joystick_cap.stl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]
2026-09-25 Prepare V2: rectangular tall buttons, corrected USB-C and scan-positioned access hole
    Complete five V1 feedback items. Preserve clean-room inputs and scan reflection, record USB assumption, verify 276 geometry checks and closed print meshes. Print supports and physical fit remain operator checks.
    [assembly.step, base.stl, button_caps.stl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]
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2026-09-25 V3 review: restore early joystick socket, flat lid and closed USB port
    Retain V2 ball with print flat and tapered internal lip. Raise lid uniformly 4mm and lengthen buttons. Add interactive transparency and browser smoke tests; 206 geometry checks pass, guessed-body dia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
    [assembly.step, base.stl, button_caps.stl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]
2026-09-25 V3 low-lid review: 1mm screen recess and rear joystick retention
    Preserve failed side-tab checkpoint. Rear heel clears chosen 10-degree lid/base/PCB scenarios; lower button wings preserve contact height. 495 required checks pass, inherited hardware-proxy diagnostics remain explicit. Browser review only; no new print files or printer request.
2026-09-25 Document and export J1 round-lip joystick experiment with known motion failures
    [joystick-cap.stl, lid-gauge.stl, two-part-test.stl]
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2026-09-25 Correct V3 lid to uniform flat face and face-down print orientation
    [lid.step, v3-flat-lid-face-down.stl]
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2026-09-25 Add J2 cap-only trial with requested 3mm round to 2.01mm square socket
    [joystick-j2-stepped-socket.stl, joystick.step]
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2026-09-25 Record corrected J3 and lowered lid print dispatch
2026-09-25 Record J3 failure and button-retention blocker for further lowering
2026-09-25 L2 translate roof down 1mm and restore exact J2 for authorized fit trial
    [joystick-j2.stl, l2-lid-and-j2.stl, lid-face-down.stl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]
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2026-09-25 L4 refine opening halfway back and 0.3mm photo-up after L3 overshoot
    [l4-lid-face-down.stl, lid.step]
2026-09-25 S1 lower seam to 2:1 split with stronger walls hidden catches and single pry
    [assembly.step, base-floor-down.stl, lid-face-down.stl]
2026-09-25 Package approved S1 full case with exact J2 and four V2 buttons
    [base-floor-down.stl, button-1.stl, button-2.stl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]
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2026-09-25 S2 tighter replacement base and rounded buttons; archive assembled S1 photo
    [assembly.step, base-floor-down.stl, button-1.stl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]
2026-09-25 Record S2 replacement base and rounded buttons print dispatch
2026-09-25 v1.0 production: S2 plus 0.25 mm nudges to joystick hole, USB-C opening and reset hole
    S2 passed Austin's physical test. Joystick throat +0.25 y (toward USB-C,
    away from LCD), USB-C aperture/recess +0.25 z, reset hole -0.25 y.
    35 checks pass; buttons and J2 byte-identical to tested parts. Not printed.
    Archives five of Austin's v1.0 photos without metadata; README points at v1.0.
    [assembly.step, base-floor-down.stl, button-1.stl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]
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2026-09-26 v1.1: 1.0 mm USB-end spacer in lid and base so the boards cannot slide
    Austin: PETG v1.0 works but the stack slides ~1.2 mm along the case and
    lines up best pushed toward the buttons. Lid lip between rails + base rail
    stops, 0.2 mm left free. Openings unchanged. 16 checks pass. Not printed.
    [assembly.step, base-floor-down.stl, lid-face-down.stl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]
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2026-09-26 v1.2: halve the USB-end spacer to 0.5 mm after v1.1 lid was too tight
    v1_1_spacer gains configure(rev, spacer); v1.1 STLs regenerate identical.
    [assembly.step, base-floor-down.stl, lid-face-down.stl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]
2026-09-26 v1.3: move USB-C end wall 0.5 mm in on lid and base, no spacer
    Austin: drop the lip/stops, just bring the wall in. Case 58.6 mm long;
    identical to v1.0 below y51. 23 checks pass.
    [assembly.step, base-floor-down.stl, lid-face-down.stl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]
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2026-09-26 Promote v1.3 to current best in stl/current with stable paths
    Austin: v1.3 holds the board, nothing rattles, everything clicks.
    [base.stl, button.stl, full-set.stl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]
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2026-09-26 v1.4 review: round lid top perimeter 1.5 mm and LCD window 0.7 mm
    Look trial for Austin; fit, base and caps unchanged from v1.3. Not printed.
    [assembly.step, lid-face-down.stl]
2026-09-26 v1.4 review 3: lid top edge 3.0 mm, LCD window 1.2 mm; base byte-identical to v1.3
    [assembly.step, lid-face-down.stl]
2026-09-26 v1.4 review 4: LCD window 1 mm smaller each side with rounded bezel over glass border
    [assembly.step, lid-face-down.stl]
2026-09-26 v1.4 joystick J4: flat 5 mm top on the ball for the press-in click
    Socket, neck, flange, ball centre unchanged from J2. Shown in v1.4 viewer.
    [assembly.step, joystick.stl]
2026-09-26 J4 review 2: joystick hat - 5.5 mm waist, 45 deg flare to 7 mm flat disc
    Same height as J2; socket and ball centre unchanged. Not printed.
    [assembly.step, joystick.stl]
2026-09-26 J4 review 3: 7.4 mm half-ball joystick, flat all the way across
    Largest ball with no new lid contact vs J2 in the 10-degree tilt scenarios
    (7.6/7.5 graze the 8 mm hole). Hat version dropped. Not printed.
    [assembly.step, joystick.stl]
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2026-09-26 Fix J4 socket: bigger ball had filled top 1.5 mm of the stick socket
    Re-cut J2's exact stepped socket after adding the 7.4 mm ball; new check
    compares the socket void to J2. Record the failed 6x J4 print and photos.
    [assembly.step, joystick.stl]
2026-09-26 Record fixed J4 joystick gray PETG print dispatch
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2026-09-26 J5 joystick: socket narrows sooner so the cap rides higher for press-in
    Round mouth shortened by 0.3 (and a 0.5 test variant); square grip and
    outside unchanged. Higher cap costs tilt room: 0.3 clear to ~9 deg, 0.5 to
    ~6 deg in the J1-CHECK scenarios. Fixed J4 kept as joystick-j4-fixed.stl.
    [assembly.step, joystick-j4-fixed.stl, joystick-j5-lift-0.3.stl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]
2026-09-26 J6 joystick test set: tighter socket (1.95/1.90) and thumb-dish variant
    For a clean centre press: cap rocked on the stem. Flange notches 1/2/3.
    [joystick-j6-a.stl, joystick-j6-abc-plate.stl, joystick-j6-b.stl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]
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2026-09-26 Record J6 socket stringing failure and cause (flat overhangs inside socket)
2026-09-26 J7 joystick test set: self-supporting socket (45 deg funnel + pyramid roof)
    J6 socket strung in PETG over its flat ledge and roof. No downward face
    steeper than 45 deg inside the socket now. A/B/C as J6.
    [joystick-j7-a.stl, joystick-j7-abc-plate.stl, joystick-j7-b.stl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]
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2026-09-27 J8 joystick set: three variations on J7-B for clean direction pushes
    1: flange 9.2; 2: flange 9.2 + lift 0.5; 3: rim edge 1.2. Notches 1/2/3.
    [joystick-j8-1.stl, joystick-j8-123-plate.stl, joystick-j8-2.stl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]
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2026-09-27 v1.4 lid: 12 crush ribs in the skirt grip the base tongue by 0.15 mm
    Lid-only change for a firmer, rattle-free hold on already-printed bases.
    [assembly.step, lid-face-down.stl]
2026-09-27 v1.5: lid 0.5 mm taller inside so J9 tips without clicking centre
    Stretch above the board hold-down; button flanges +0.5; joystick hole edge
    rounded 0.6. J9 clears the lid at 10 deg tilt. Base unchanged. Not printed.
    [assembly.step, button.stl, joystick-j9.stl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]
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2026-09-27 Promote v1.5 to current best: v1.5 lid, v1.3 base, J9 joystick, original buttons
    Austin: everything works. Drop the thicker v1.5 button; original caps fit.
    [assembly.step, button.stl, full-set.stl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]
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2026-10-02 J24-FIT test: three J22 caps with longer tight grip (0.75/0.95/1.65); dropped
    [joystick-j24-fit-1.stl, joystick-j24-fit-2.stl, joystick-j24-fit-3.stl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]
2026-10-02 J24-FIT result: hole 2 wins; still rips out (flange too small)
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2026-10-08 AW1: Atomic Wedgie base v1 (RP2040-Plus BOOT/RESET + battery slot)
    [base-floor-down.stl]
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2026-10-09 AW-R: three shorter square RESET test caps
    [reset-1-notch.stl, reset-2-notch.stl, reset-3-notch.stl]
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2026-10-09 RESET v3 test: three shorter caps
    [reset-v3-1-notch.stl, reset-v3-2-notch.stl, reset-v3-3-notch.stl]
2026-10-09 RESET button v3 final: 0.90 shorter than v2; 10 dropped
    [reset-button.stl]
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
